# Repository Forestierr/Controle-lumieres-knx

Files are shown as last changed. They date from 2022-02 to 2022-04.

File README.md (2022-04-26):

# controle des lumieres KNX

Controle des lumières de l'atelier ELO avec un écran tactile, un Raspberry et des module ABB et KNX.

L'interace graphique est un site web, réalisé en Python avec Flask.

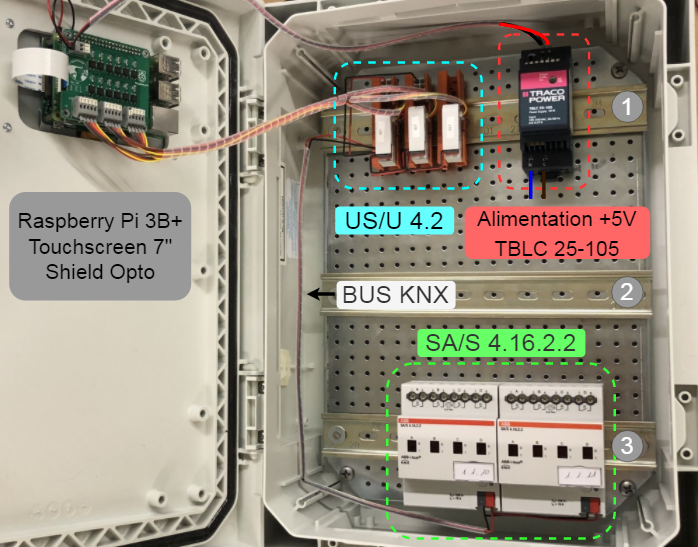
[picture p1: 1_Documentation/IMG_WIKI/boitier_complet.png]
img boitier


##

youtube : https://www.youtube.com/channel/UC0hVF6m1WlG9nCOo1_hOlJg

site : [Zappvion](http://www.zappvion.ch)

## ##
    
<div align="center">
    <i>Robin Forestier</i>
</div>

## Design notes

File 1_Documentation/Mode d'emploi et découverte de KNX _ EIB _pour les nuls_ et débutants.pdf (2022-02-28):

Rechercher

Modes de sujets

mil3d (http://www.knx-fr.com/member.php?action=profile&uid=32)
Super Moderator

Messages : 939
Sujets : 15
Inscription : Jun 2011
Réputation : 0 (http://www.knx-fr.com/reputation.php?uid=32)

#1 (http://www.knx-fr.com/showthread.php?tid=2129&pid=14907#pid14907)

Pages (10) : 1 | 2 (http://www.knx-fr.com/showthread.php?tid=2129&page=2) | 3 (http://www.knx-fr.com/showthread.php?tid=2129&page=3) | 4 (http://www.knx-fr.com/showthread.php?tid=2129&page=4) | 5 (http://www.knx-fr.com/showthread.php?tid=2129&page=5) ... 10 (http://www.knx-fr.com/showthread.php?tid=2129&page=10) | Suivant » (http://www.knx-fr.com/showthread.php?tid=2129&page=2) | Note de ce sujet :
Recherche (http://www.knx-fr.com/index.php) | Liste des membres (http://www.knx-fr.com/memberlist.php) | Carte des membres (http://www.knx-fr.com/usermap.php) | Calendrier (http://www.knx-fr.com/calendar.php) | Aide (http://www.knx-fr.com/misc.php?action=help)
Bienvenue, Visiteur ! | Connexion (http://www.knx-fr.com/member.php?action=login) | S’enregistrer (http://www.knx-fr.com/member.php?action=register)

Forum KNX francophone / English KNX forum (http://www.knx-fr.com/index.php) › Français (http://www.knx-fr.com/forumdisplay.php?fid=3) › Matériel KNX (http://www.knx-fr.com/forumdisplay.php?fid=5)
Mode d'emploi et découverte de KNX / EIB "pour les nuls" et débutants

Mode d'emploi et découverte de KNX / EIB "pour les nuls" et débutants

02/02/2012, 14:00:58 (Modification du message : 07/01/2021, 14:46:56 par filou59.) (http://www.knx-fr.com/member.php?action=profile&uid=1754)

--------------- Afin de préserver ce sujet, merci de ne pas poster ici vos demandes personnelles mais de créer un nouveau sujet ---------------

Bonjour à tous,

Voici un premier essai de présentation de KNX "pour les nuls" et les débutants en électricité et domotique KNX.
Je vais essayer de vous présenter cette très belle technologie appliquée à la domotique résidentielle.

Loin de moi l'idée de me présenter en spécialiste du KNX, ma seule volonté est ici de dégrossir le terrain pour le vrai débutant en KNX qui ne comprend rien à ce qui se dit sur ce forum, et je sais que c'est le cas de beaucoup de nouveaux membres.

Bon courage et bonne découverte !

La théorie... (rapidement !)

Le KNX (anciennement EIB) est un standard de communication appliqué à la domotique résidentielle et industrielle.

Ses points forts?
C'est d'être un standard multimarque, non cantonné à un seul fabriquant (contrairement à la plupart des "standards" en domotique). Le cahier des charges que chaque fabriquant doit suivre et respecter pour apposer le logo KNX sur son produit est très strict, les tests avant validation sont poussés. La qualité des produits semble au rendez-vous tant au niveau de la fiabilité qu'au niveau des possibilités offertes.

Un autre point fort et qui est une spécificité du KNX (même s'il n'est pas le seul l'utilisant), c'est qu'il fonctionne sur le principe de multiples petites intelligences qui communiquent entres-elles plutôt que sur le principe d'un seul cerveau central, qui, en cas de panne, peut rendre toute une installation domotique hors service.

Son point faible ?
Le prix de certains composants (mais souvent à l'image des possibilités et de la qualité offerte).
Bien que vous verrez qu'en choissisant bien ses composants, ce qui semblait impossible peut au final être plus réalisable que prévu.

Bref, le KNX, vous payez le prix,... mais vous êtes rarement déçu.

La pratique... (déjà ?)

Comment allumer une lampe en KNX?
Vous avez besoins de quelques composants indispensables, simplement pour allumer et éteindre une lampe en KNX.
Les voici : (avec leur tarif, ça peut aider tout de suite à savoir si c'est réalisable pour vous ou pas )
1) une lampe avec une ampoule dedans (et qui fonctionne,... oui oui,... c'est indispensable) ; 5 € ça... ça va...
2) un module actionneur KNX (aussi appelé "actuateur") qui actionnera la lampe en ON ou OFF ; à partir de 20€ (si achetés "par 16")
3) un interrupteur : soit un interrupteur KNX, soit un interrupteur bouton poussoir classique (qu'on trouve dans tous les supermarchés) derrière lequel vous placerez un genre "d'adaptateur" KNX ; à partir de 40€ l'interrupteur, pour les plus simples
4) un câble au standard KNX (ou pas) qui reliera tous les participants KNX entre eux (interrupteur, actionneur et alimentation). Il s'agit d'un câble de type câble réseau de couleur verte dont seuls 2 fils sont utilisés (le rouge et le noir); 0,40€/m
5) une alimentation 30V : ceci est plus spécifique à la norme KNX, vous aurez en effet besoin d'une alimentation/d'un transfo pour mettre tout ce beau monde en route, pour les alimenter en électricité via le câble KNX. Attention, on ne parle pas ici d'alimenter l'ampoule, mais bien d'alimenter en 30v les différents modules KNX pour qu'ils puissent fonctionner. Ils seront alimentés en 30v via les 2 fils du câble KNX. Il faut donc que ce câble vert passe aussi par cette alimentation. 170€ l'alimentation pour une petite installation !... mais comptez plutôt 230€ ! Mais pourquoi c'est si cher ??? Je ne sais toujours pas...
6) un peu de câble électrique pour relier les différents appareils en 220v

Voilà, vous avez avec ceci tout ce qu'il faut pour allumer et éteindre une ampoule en KNX (presque tout..., nous le verrons plus bas).

Voici le schéma de montage :

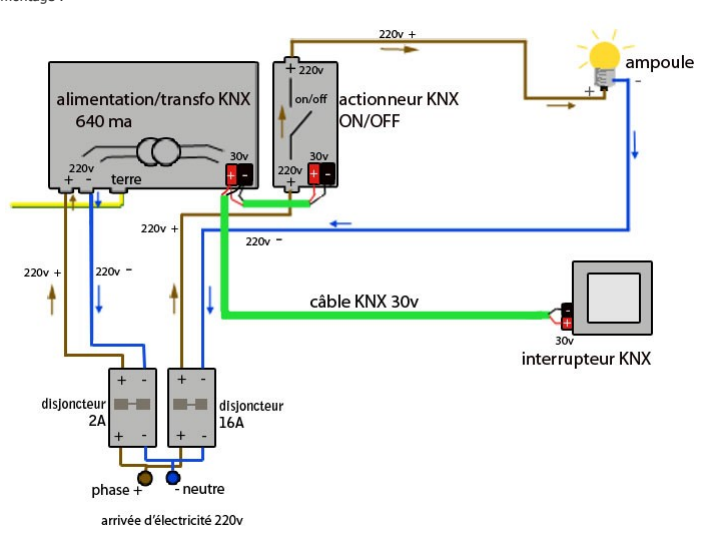
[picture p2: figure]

Quelques explications sur ce schéma :

* L'alimentation KNX (le transfo) transforme donc le 220v en 30v et le transmet via le câble vert à tous les modules KNX. Tous les modules KNX qui s'y trouvent connectés peuvent donc fonctionner.

* Les petits plots rouge et noir que vous voyez sur tous les modules KNX sont des connecteurs WAGO. (http://www.wagocatalog.com/okv3/index.asp?cid=1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) Ils permettent de connecter le câble KNX vert de toutes les manières possibles entre les différents modules KNX. Il y a en effet une très grande liberté dans la manière dont ce câble KNX vert passe d'un module à l'autre. Du moment que vous respectez la polarité +/- (les couleurs des fils rouge/noir), vous pouvez les connecter en parallèle, en étoile, en série,... tout est permis (dans la limite du respect de la norme, notamment sur les longueurs maximum de câble,... que vous n'atteindrez jamais dans une maison). Attention aussi de ne jamais créer de boucle fermée avec le câble KNX !
Grâce à ces plots rouge et noir, vous pouvez connecter jusqu'à 4 câbles vert différents par module KNX, ce qui vous permet une très grande liberté dans le déploiement du câble KNX dans toute la maison. Vous pouvez également acheter d'autres WAGOs de ce type et en placer n'importe où sur le câble pour le "spliter".

* Ce câble vert sert donc à alimenter les modules KNX, mais il sert aussi aux modules pour communiquer entre-eux.
Chaque module KNX possède en effet sa propre intelligence qui lui permet d'envoyer des messages et d'en recevoir, mais aussi de les interpréter pour agir en conséquence.

Dans cet exemple-ci, lorsqu'on va appuyer sur l'interrupteur KNX, celui-ci va envoyer un message 'ON' sur le câble vert (on dit qu'il envoi un message sur le BUS). (http://fr.wikipedia.org/wiki/R%C3%A9seau_en_bus) Tous les modules présents sur ce câble vert (sur le BUS) vont recevoir le message 'ON', mais seul le module actionneur va tenir compte du message et va allumer la lampe. Il est le seul à tenir compte du message parce que vous l'aurez programmé comme cela. Vous aurez programmé le module actionneur pour réagir au message envoyé par cet interrupteur là.

Voici une autre manière très parlante d'exprimer ce qui se passe sur le bus, proposé par un membre du forum (silverrcx) : Le câble vert est un "bus" de donnée, donc tout le monde y va de son petit message, tout le monde le reçoit et n'en fait rien (souvent) ou qqch (parfois). Quand tu appuie sur la touche de l'interrupteur, il "crie" [bouton 23 appuyé] sur le bus et il y a (ou pas) un récepteur (souvent un relais) qui se dit "ah mais dis donc 23 c'est moi ça! Paf j'enclenche le relais".

* Autre détail sur le schéma : pour ceux qui débutent en électricité, vous remarquez que seul le câble + passe par l'actionneur KNX. En effet, pour allumer ou éteindre une lampe, il suffit d'ouvrir ou de fermer un seul fil pour que la lampe s'allume ou s'éteigne. Il n'est donc pas nécessaire de faire passer les 2 fils + et - via l'actionneur KNX. Le câble - va directement à l'ampoule.
Ce principe n'a rien à voir avec la domotique, c'est un principe classique en électricité, appliqué à (presque) tous les interrupteurs classiques dans une maison (exceptés les interrupteurs dis bi-polaires).

* les disjoncteurs se branchent toujours avant tout actionneur (ou dimmer) KNX. Il faut voir les modules KNX comme des interrupteurs classiques, qui sont toujours branchés après les disjoncteurs.

* Il faut également mettre l'alimentation sur un disjoncteur, et de préférence un disjoncteur à part. Comme ça en cas de problème sur une ligne d'éclairage (cours circuit pendant que vous changez une ampoule par ex.), toute l'installation KNX n'est pas coupée à cause du disjoncteur de la ligne d'éclairage qui au sauté.
Le disjoncteur 2A sur le schéma est suffisant dans ce cas car il n'y a que l'alimentation KNX dessus. Mais vous auriez pu mettre un disjoncteur 16A. Il faut savoir qu'un disjoncteur ne sert pas à protéger le matériel qui est branché après lui mais simplement à protéger le câble de toute surtension. En effet, si vous branchez un moteur de 10.000w (ou 5 de 2000w) sur un câble 2,5mm², le câble va fondre. Le disjoncteur sert donc à couper l'alimentation en cas de trop forte demande sur le câble.

Il ne faut pas non plus sous-dimensionner le disjoncteur car sinon quand vous brancherez du matériel de trop forte puissance le disjoncteur sautera. Il faut dimensionner un disjoncteur par rapport au câble qui est utilisé après lui (1,5 - 2,5 - 6 ou 10 mm²,), mais aussi par rapport à ce qui sera demandé comme puissance sur le câble.

Ne pas hésiter à demander l'aide d'un électricien quand on ne connait pas bien les règles de dimensionnement des disjoncteurs, câbles, différentiels, etc. Ce n'est pas évident, c'est un métier. Je peux donner quelques conseils, mais je ne pousserais pas quelqu'un à faire ça tout seul, ça peut être dangereux. Surtout que les règles changent et sont différentes d'un pays à l'autre !

Je sens qu'il manque quelques chose pour faire fonctionner mon installation... Ho zut, c'était trop beau!...

En effet,... si tout est déjà programmé, ce qui est présenté ci-dessus fonctionnera très bien. Mais le soucis, c'est qu'il faut bien les programmer tous ces modules KNX la première fois que vous allez les installer. Et là c'est un peu plus difficile à avaler pour le portefeuille!

* Il existe différents systèmes pour programmer les modules KNX. Le plus communément utilisé, c'est le PC sur lequel vous aurez installé LE programme INDISPENSABLE vendu par l'association KNX.org. Ce programme c'est ETS (actuellement version 5.0, mais les versions 3.0f et 4 sont toujours utilisées). Il s'agit d'un programme qui a été créé au départ pour les professionnels de la domotique, qui gagnent de l'argent avec leur entreprise. Vous ne vous étonnerez donc pas qu'ETS soit vendu près de 1000€ HT ! Impensable me direz-vous ? Il est pourtant indispensable pour programmer votre installation. Une solution est de trouver une âme charitable qui pourra vous prêter sa licence le temps de programmer votre installation. Essayez éventuellement via ce forum, en contactant directement un forumeur près de chez vous... sans garantie bien entendu.
Il est aussi possible d'acquérir une licence ETS lite à 200€ (http://www.knx.org/be-fr/logiciel/ets/prix/index.php) (voir moins cher pour ceux qui souhaitent passer le ETS eCampus) (http://www.knx.org/be-fr/formation/knx-eacademy/ets-ecampus/index.php) qui peut convenir pour une petit projet de type résidentiel même s'il dépasse les 20 participants (en créant plusieurs projets ETS qui utilisent les mêmes adresses de groupe).

* Ce qu'il manque aussi à l'installation décrite sur le schéma ci-dessus, c'est le moyen de faire communiquer le PC (et son programme ETS) avec les modules KNX. Pour cela, vous devez acquérir un module USB ou Ethernet (IP) qui servira de passerelle (+- 180€).
Là, vous n'y couperez pas, c'est non seulement utile pour programmer les modules KNX, mais aussi si vous souhaitez profiter de votre installation et de toutes ses possibilités de communication vers l'extérieur.
Cela permettra par exemple de mettre en place ce qui est communément appelé sur le forum 'une visu', soit une interface visuelle sur PC ou tout autre solution à base d'écran, qui permet d'avoir un aperçu, un suivi visuel de toute votre installation domotique.

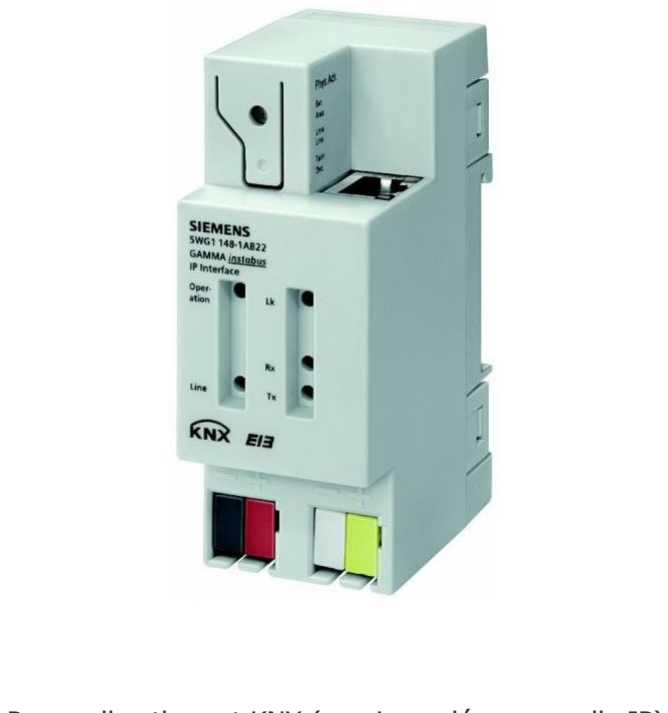
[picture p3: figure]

Passerelle ethernet KNX (aussi appelée passerelle IP)

ATTENTION lors de vos achats de ne pas confondre passerelle IP KNX (ou interface IP KNX) et Routeur KNX.
- la passerelle IP KNX (ou interface IP KNX) est ce dont vous avez besoin pour programmer vos modules KNX sur le BUS ou pour faire de la "visualisation"
- le routeur/coupleur IP KNX sert à faire communiquer 2 bâtiments qui auraient chacun une ligne KNX et dont le seul lien physique possible est un câble réseau ethernet. Cela crée un "tunnel IP" dans lequel passent les messages KNX d'une ligne de bus KNX à l'autre. En plus de cette fonction, certains routeurs IP permettent malgré tout une utilisation comme interface de programmation via ETS ou pour faire de la visualisation.

La fin... (déjà ?)

Voici que se termine un premier aperçu d'une installation simple en KNX. Avec cela, vous pouvez déjà comprendre comment cela fonctionne et les grands principes du système EIB/KNX. A partir de là, vous comprendrez peut-être un peu mieux de quoi discutent tous ces forumeurs aguéris qui balancent des termes comme BUS, visu, actuateurs, etc.

La suite..! La suite....!!

Quelques informations lancées (jetées) au hasard pour les débutants :

Les différentes alimentations
Les alimentations KNX existent en 160ma (milliampère), 320ma et 640ma. Les modules KNX, pour être certifiés, doivent consommer au maximum 10ma chacun. Vous pouvez donc déduire avec cela qu'une alimentation de 160ma peut faire fonctionner sur sa ligne (son câble vert) 16 modules au
maximum, une de 320ma, 32 modules et une de 640ma, 64 modules. Si vous avez un minimum de moyens, achetez directement une 640ma, on arrive vite à 64 modules dans une maison.
Si vous avez plus de 64 modules dans votre maison, vous devez utiliser un coupleur de ligne.

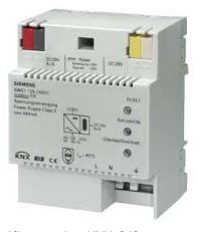
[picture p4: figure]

Alimentation KNX 640ma

Sur cette alimentation, vous voyez le WAGO rouge et noir, mais il y a aussi un WAGO blanc et jaune. En effet, certains modules KNX ne peuvent pas se contenter des 10ma qu'ils sont autorisés à prendre sur le BUS pour fonctionner. On doit donc leur adjoindre une alimentation secondaire 30v. L'exemple type, c'est la passerelle IP que vous pouvez voir plus haut. Elle possède aussi les WAGOs blanc et jaune. Il suffit d'utiliser les fils blanc et jaune du câble vert KNX pour alimenter secondairement la passerelle IP. Ces fils blanc et jaune ne sont actuellement pas utilisés en domotique KNX. Ils sont là "pour réserve" en cas d'évolution de la norme.

*Attention que cette sortie 30v secondaire n'a pas les mêmes propriétés que la sortie 30v rouge et noir du BUS KNX. Elle ne peut pas être utilisée pour cela.
*Attention aussi que toutes les alimentations KNX n'ont pas de sortie 30v secondaire.
*Certaines alimentations ont par contre 2 sorties 30v rouge et noir pour alimenter 2 lignes de BUS différentes (il faudra utiliser malgré tout un coupleur de BUS)
pff, c'est compliqué tout ça !!

Le coupleur de ligne (coupleur de BUS)
Il existe des coupleurs de ligne. Une ligne KNX est l'ensemble des modules KNX connectés entre-eux par "le même" câble KNX. Comme on peut avoir maximum 64 participants (modules KNX) sur une ligne puisque les alimentations font maximum 640ma, vous pouvez utiliser ces coupleurs de ligne pour que 2 lignes puissent communiquer entres-elles. En effet sans cela, un message envoyé par un participant situé sur la ligne 1 (sur l'alimentation n°1) n'arriverait jamais au participant situés sur la ligne 2 (sur l'alimentation n°2) qui attend ce message.

Il existe aussi un type de coupleur de ligne via réseau IP que l'on appelle routeur/coupleur IP KNX. Comme dit plus haut (à propos des interfaces IP KNX), il sert à faire communiquer 2 bâtiments qui auraient chacun une ligne KNX et dont le seul lien physique possible est un câble réseau ethernet. Cela crée un "tunnel IP" dans lequel passent les messages KNX d'une ligne de bus KNX à l'autre.

C'est quoi "une entrée KNX"?... et "une sortie"?
En domotique KNX, on parle souvent "d'entrées" et de "sorties" KNX :

Grossièrement, une "sortie KNX" c'est un module KNX fait pour effectuer une action suite à un ordre/un message KNX. Exemples de sorties KNX :
- les actionneurs (comme présenté sur l'exemple ci-dessus)
- les dimmers.

Les entrées KNX sont l'inverse. Elles sont faites pour "écouter" une action extérieure au KNX et crée un message/un ordre à partir de ce quelle ont reçu comme information "de l'extérieur".
Exemples d'entrées KNX :
- un interrupteur KNX attend qu'on lui pousse dessus pour envoyer l'ordre sur le BUS KNX d'allumer une lampe;
- un modules KNX détecteur de mouvement enverra sur le BUS KNX l'ordre d'allumer une lampe quand il verra passer quelqu'un;
- un module détecteur de température enverra sur le BUS KNX l'ordre d'allumer le chauffage lorsque une t° donnée sera atteinte.

Où trouver mon matériel?
Vous pourrez normalement trouver votre matériel auprès d'un revendeur en électricité un peu spécialisé près de chez vous. Mais le marché KNX est assez peu développé en France et en Belgique ce qui a tendance à tirer les prix vers le haut.

Par contre en Allemagne, c'est le contraire. Beaucoup de forumeur achète leur matériel en Allemagne via internet. C'est souvent moins cher et le service est toujours de qualité (d'après mon expérience).
--> Voici le site le plus connus : www.eibmarkt.com.
Ils font de très bons prix, mais ce n'est pas évident de trouver un article à cause d'un site pas très pratique à utiliser.
--> Ebay Allemagne (http://www.ebay.de) est très fourni en matériel KNX d'occasion. Il faut par contre savoir parler Allemand (plus difficile)... ou savoir utiliser GoogleTranslate (plus facile ). Utilisez les mots-clés EIB ou KNX pour trouver tous les articles KNX.

Petite aide déjà : en allemand,
- actionneur se dit "Schaltaktor",
- dimmer se dit "Dimmaktor".
- "4fach" se traduit par x4 (fois 4)
Donc "Schaltaktor 4fach" veut dire que c'est un actionneur possédant 4 sorties.

Je pense que certains revendeurs ou sites internet en France tentent de s'aligner sur les prix Eibmarkt. A vous de comparer et éventuellement d'essayer de négocier. Je ne peux pas vous guider n'ayant pas essayé.

La problématique des interrupteurs en KNX
Le choix d'un interrupteur en KNX est un vrai dilemme. Entre prix, esthétique, fonctionnalité,... rien n'est simple ! Il y a tellement de possibilités et de choix à faire. Le plus important est de savoir ce que vous voulez réellement faire aux différents endroits où vous en placerez un. Il reste à trouver celui qui rassemblera tous vos critères.

Attention que lorsque vous avez choisi une marque et un modèle d'interrupteur précis, ils sont bien souvent (pas toujours) vendu en 2 pièces détachées :
- L'interrupteur en lui même qui ne représente bien souvent que la partie visible, décorative, placée devant le mur ;
- Le coupleur de bus qui est la partie derrière l'interrupteur qui sert à communiquer avec le BUS KNX, à envoyer les ordres/messages aux autres pariticipants KNX.
Ne vous laissez pas abuser par des interrupteurs dit KNX à 25 euros, qui ne représente souvent que la partie visible auquel il faudra ajouter le coupleur de BUS.

Certains interrupteurs sont très complexes avec écran "de visualisation", thermostat, écran tactile,... les prix sont en correspondance avec la complexité.

La solution que j'ai retenue pour ma part, c'est d'utiliser un interrupteur classique de type bouton poussoir qu'on trouve dans le commerce. Ce choix je l'ai fait principalement pour raison esthétique (je n'aime pas l'esthétique de la plupart des interrupteurs KNX abordables).
Pour communiquer avec le BUS KNX, j'utilise un module d'entrée KNX (voir ci-dessus ce qu'est une entrée KNX) que je place derrière l'interrupteur. Ce module d'entrée est alimenté par le BUS KNX, il n'a donc besoin de rien d'autre que le câble KNX vert pour fonctionner. En plus des WAGOs rouge et noir qui servent à se connecter au BUS, il possède 2 fils que je connecte au bouton poussoir et qui lui serviront à détecter tout appuis sur ledit bouton. A moi de programmer les actions à effectuer selon les appuis détectés.

Les modules que j'ai retenus sont des ABB US/U 2.2, US/U 4.2 et US/U 12.2 (pour 2, 4 ou 12 entrée/sorties possibles).
Pourquoi "entrées/sorties"? Parce qu'en plus de pouvoir détecter l'appui sur un bouton poussoir, ces modules ABB US/U sont capables aussi d'allumer une led "à la demande". Ces leds, en les plaçant juste derrière la "fenêtre" de l'interrupteur, permettent de signaler l'un ou l'autre évènement aux personnes situées dans la pièce (oubli d'une lampe dans la cave,...)

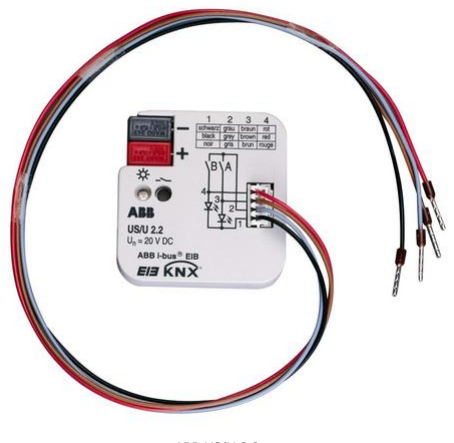
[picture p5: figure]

ABB US/U 2.2

Quel câble KNX ?
Pour votre câble KNX, vous pouvez utiliser du câble certifié KNX (le fameux câble vert). C'est franchement recommandé.
Mais à 0.40 € le mètre, certains souhaitent économiser sur ce point. Ils utilisent donc du câble réseau CAT5e, bien moins cher. Apparemment ça fonctionne. Attention d'utiliser du câble réseau avec des brins rigides, pas de brins souples. Sinon ils ne rentreront pas dans les wagos rouge et noir.

KNX, ça existe sans fil ?
Oui il existe plusieurs solutions de KNX sans fil par onde radio, mais ce sont plutôt des sous réseaux au sein du protocole KNX.

En effet, lorsque vous choisissez une marque d'émetteur/récepteur sans fil (le module KNX qui servira de passerelle entre les modules sans fil et le réseau KNX filaire), seuls les modules sans fil de cette marque là pourront passer par l'émetteur/récepteur en question. En clair, si vous choisissez un émetteur/récepteur HAGER, vous devrez acheter les télécommandes de la marque Hager.

Mais une fois le lien entre le réseau filaire KNX et le réseau sans fil effectué grâce à l'émetteur/récepteur, la communication est transparente entre les modules KNX filaires et les modules KNX sans fil (pour certaines marques tout du moins, pas dans toutes les marques !)

L'exemple d'un très bon réseau sans fil que je connais et que j'utilise quotidiennement est le réseau sans fil Hager avec son coupleur de média TR131a (http://www.eibmarkt.com/cgi-bin/eibmarkt.storefront/EN/Product/NS6509694?PID=EN_NS6509694) (émetteur/récepteur). Associé aux télécommandes TU402, (http://www.eibmarkt.com/cgi-bin/eibmarkt.storefront/EN/Product/NS6508682?PID=EN_NS6508682) TU404, (http://www.eibmarkt.com/cgi-bin/eibmarkt.storefront/EN/Product/NS6508683?PID=EN_NS6508683) TU406 (http://www.eibmarkt.com/cgi-bin/eibmarkt.storefront/EN/Product/NS6508684?PID=EN_NS6508684) et TU418 (http://www.eibmarkt.com/cgi-bin/eibmarkt.storefront/EN/Product/NS6508685?PID=EN_NS6508685) (pour 2, 4, 6 et 18 boutons), cela fait un très efficace réseau sans fil pour télécommander la maison.
Ces télécommandes sont très esthétiques (question de goût), et très efficaces point de vue longueur de portée (au fond de mon jardin à 60m, j'allume toujours la lampe du salon).

Il existe chez Hager d'autres modules d'entrées sans fils que les télécommandes pré-citées : boutons poussoirs, modules d'entrées à contacts secs,... ainsi que des modules de sorties sans fil : actionneurs, dimmers,...

Attention encore une fois que toutes les marques ne permettent pas une communication bi-canal (émetteur/récepteur). Certaines se limitent en effet au simple transfert des messages KNX venant du réseau sans fil vers le KNX filaire et ne permettent donc pas l'envoi d'ordres KNX venant du filaire vers le réseau KNX sans fil. Cela fait une grande différence de souplesse (par exemple en cas de souhait d'évolution de votre installation domotique, si vous souhaitez installer un jour un actionneur à un endroit non prévu à l'origine et qu'il n'y a pas de câble KNX vert à proximité).

Quel matériel de base choisir dans tout ce choix de marque et de modèle?
Voici quelques exemples concrets de matériel KNX à prix raisonnable, pour des fonctionnalités classiques et approuvées :
Alimentation Siemens 640ma 5WG1125-1AB21 (http://www.eibmarkt.com/cgi-bin/eibmarkt.storefront/EN/Product/NS0821503?PID=EN_NS0821503)
Passerelle IP Siemens 5WG1148-1AB22 (http://www.eibmarkt.com/cgi-bin/eibmarkt.storefront/EN/Product/NS6508760?PID=EN_NS6508760) Cette passerelle IP a longtemps été recommandée car elle est très répandue sur le marché KNX, ce qui la rend compatible de manière plus sûr dans la plupart des applications ("visus", matériel,...). Elle semble cependant aujourd'hui détrônée par des passerelles plus récentes. Un post sur le forum créé par Filou59 l'explique en détail ici (http://www.knx-fr.com/showthread.php?tid=6485)

Edit 10/2020 : Ce modele est enfin arrété par Siemens, raison de plus pour ne plus le choisir même si certains fournisseur la propose encore.

Actionneur On/Off Siemens 16 sorties 5WG1567-1AB22 (http://www.eibmarkt.com/cgi-bin/eibmarkt.storefront/EN/Product/NS6508387?PID=EN_NS6508387)
Module dimmer JUNG FUD 4252 4 sorties 50w-210w (http://www.eibmarkt.com/cgi-bin/eibmarkt.storefront/EN/Product/NS6506531?PID=EN_NS6506531)

Module d'entrée/sortie ABB US/U 2.2 (http://www.eibmarkt.com/cgi-bin/eibmarkt.storefront/EN/Product/NS0819733?PID=EN_NS0819733) pour, par exemple, interrupteur
Détecteur de présence 360° et mesure de luminosité (http://www.eibmarkt.com/cgi-bin/eibmarkt.storefront/EN/Product/N000530?PID=EN_N000530) de marque Eibmarkt (attention, ce n'est pas un détecteur de mouvement, c'est plus sensible !) Câble KNX vert par 100m (http://www.eibmarkt.com/cgi-bin/eibmarkt.storefront/EN/Product/NS0140116?PID=EN_NS0140116)
Pour le KNX sans fil de marque HAGER, voir les liens au point précédent

C'est quoi une "platine de test"? à quoi ça sert?
Avant de vous lancer dans l'achat de tout votre matériel KNX qui peut coûter des milliers d'euros, il serait vraiment très sage d'acheter quelques éléments pour les tester, pour vérifier qu'ils fonctionnent ensembles et comme vous le souhaitez. Achetez au minimum le matériel décrit dans l'exemple du début de ce post + un exemplaire des quelques éléments spécifiques à votre installation que vous souhaitez intégrer.

Une fois que tout aura été testé et validé, que vous vous sentirez à l'aise avec vos choix et la programmation des modules, il sera bien temps de vider votre compte en banque en achetant le reste.

Comment savoir si un module KNX me conviendra?
Vous avez de la chance, avant d'acheter un module KNX vous pouvez savoir tout ce qu'il a dans le ventre, du moins en termes de fonctionnalités.

Le cher (!) programme ETS nécessaire à la programmation des modules KNX permet en effet de visualiser toutes les fonctionnalités d'un module KNX que vous ne posséderiez pas encore. Il suffit pour cela d'aller sur le site internet du fabriquant du module en question et de télécharger sa base de données de produits KNX. Vous intégrez cette base de données dans la base de données ETS et vous pouvez ainsi avoir accès à toutes les propriétés et possibilités des différents produits.

Par exemple, vous pourrez savoir si un dimmer permet l'allumage d'une lampe sur 10 secondes, savoir si un interrupteur permet une action spécifique sur un double appui, etc...

Et pour la partie visualisation de mon installation (la visu)?
Le trio de logiciel libre le plus connu sur ce forum est EIBd, LinkKNX et KNXweb (dans sa version 2 actuellement). Une section entière leur est consacrée. (http://www.knx-fr.com/forumdisplay.php?fid=10)
Mais vous avez aussi des solutions toutes prêtes comme le Gira HomeServer, Domovea, LifeDomus,... (désolé pour les autres, j'ai pas fait d'enquête) Pour les programmeurs sous Windows, vous pouvez aussi créer votre propre programme pour gérer votre installation grâce au SDK Falcon.net créé par l'association KNX (il est gratuit)

Tutoriel ETS 3.0 et tutoriel ETS 4

Un tutoriel ETS 3.0 : http://sitelec.org/download_page.php?fil...ts_erm.pdf

Et un très bon tutoriel ETS 4.0 (et KNX en général) proposé par un membre du forum : Le sujet de discussion : http://www.knx-fr.com/showthread.php?tid=2241
Le tutoriel en question : http://www.knx-fr.com/attachment.php?aid=84

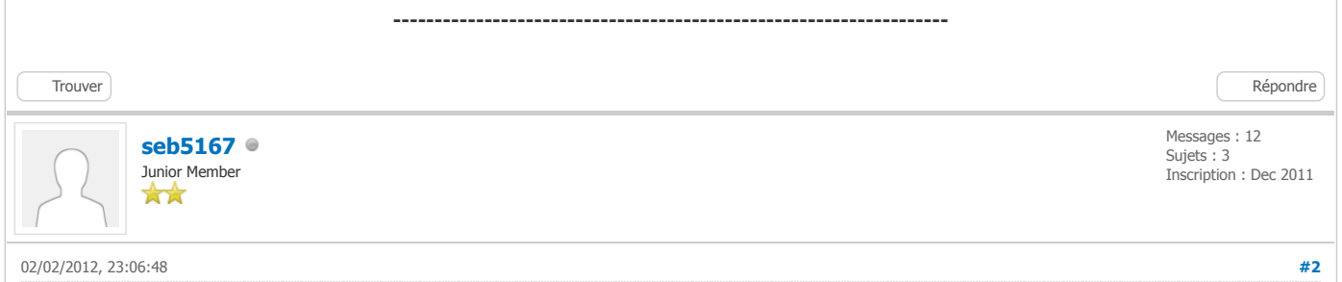
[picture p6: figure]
Trouver; Répondre; seb5167; Junior Member; Messages : 12 Sujets : 3 Inscription : Dec 2011

Waou!! joli post ! merci mil3d
J'avais déjà tout découvert tout seul ou presque. Tu aurais pu venir 8mois plus tôt

Concernant la visu, j'utilise ligo.tv c'est le seul que j'ai réussi à faire fonctionner malgré les dizaines heures passées sur linknx et knxweb.
Non de dieu, quand y aura t il quelqu'un qui postera un VM fonctionnelle avec un ubuntu récent le trio infernal (pour moi) et des lignes de commandes

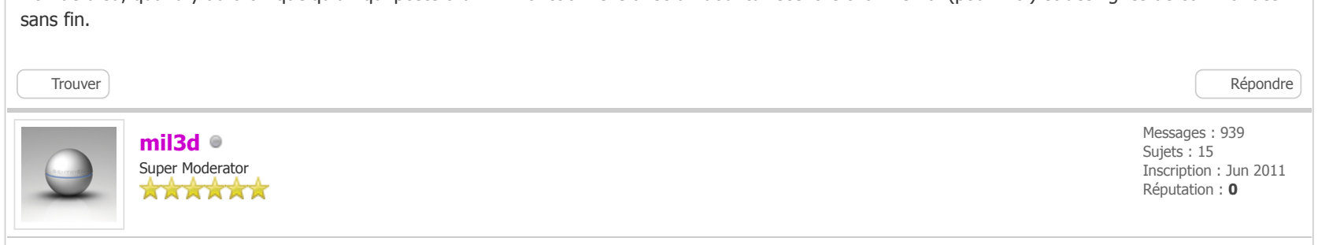
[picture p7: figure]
Trouver; Répondre; mil3d; Super Moderator; Messages : 939 Sujets : 15 Inscription : Jun 2011 Réputation : 0; sans fin.

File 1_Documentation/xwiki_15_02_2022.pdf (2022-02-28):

# Controle des lumières KNX

last modified by Forestier Robin
on 2022/02/22 08:19

Projets - Controle des lumières KNX

- 1.0 - But
- 2.0 - Liens
- 3.0 - Composants
- 4.0 - Schéma Bloc
- 5.0 - Shield Opto
- 5.1 - Shéma Shield Opto
- 5.2 - PCB Shield Opto
- 6.0 - GUI
- 6.1 - Utilisateurs
- 6.2 - Pages
- 6.2.1 - Login
- 6.2.2 - page1
- 6.2.3 page 2
- 6.2.4 - Settings
- 6.2.5 - téléphone
- 7.0 - Programmation
- 7.1 - Code Python
- 7.1.1 - Config
- 7.2 - HTML
- 7.3 - CSS
- 8.0 - Instalation du Raspberry
- 8.1 - Instalation
- 8.1.1 - Image
- 8.1.2 - Git clone
- 8.1.3 - Configuration
- 8.1.4 - Configuration Gunicorn
- 8.1.5 - Création du certificat SSL
- 8.1.6 - Configuration NGINX
- 8.1.7 - Lancement Navigateur
- 9.0 - Sauvgarde de l'image
- 9.0 - Câblage
- 10.0 - Mécanique
- 10.1 - Fixation

Page 2 / 24 - last modified by Forestier Robin on 2022/02/22 08:19

# 1.0 - But

Le but de ce projet est de réaliser une interface graphique pour le contrôle des lumières de l'atelier.
Un écran Raspberry Pi 7" Touchscreen Display servira de contrôleur principal, directement branché sur un Raspberry Pi 3b+.
Une interface à l'aide d'optocoupleurs est utilisée et directement contrôlé par les GPIO du Raspberry.
Pour le contrôle des lumières, nous utilisons deux types de module, trois US/U 4.2 de ABB et deux SA/S 4.16.2.2.

# 2.0 - Liens

Gitlab (http://http://172.16.32.230/Forestier/controle-des-lumieres-knx)
ABB - US/U 4.2 (https://new.abb.com/products/fr/GHQ6310070R0111/us-u4-2)
ABB - SA/S 4.16.2.2 (https://new.abb.com/products/fr/2CDG110262R0011/sa-s4-16-2-2)
Explication KNX (http://www.knx-fr.com/showthread.php?tid=2129)

# 3.0 - Composants

Pour le projet :
Nom | Nombre | Prix unité | Prix tolal
Raspberry Pi 3B+ | 1 | 40.90 | 40.90
Raspberry Pi 7" Touchscreen 1 | 74.90 | 74.90
US/U 4.2 | 3 | 83.80 | 251.40
SA/S 4.16.2.2 | 2 | 169.60 | 339.20
TBLC 25-105 | 1 | 52.00 | 52.00
Fibox ARCA 403015 | 1 | 96.90 | 96.90
Total | | | 857.30
Pour la carte Shield Opto :
Reference | Value | Prix unité | Prix total
K2-K13 | ASSR-1218 | 1.75 | 21
x1-x3 | WAGO 218-505 | 3.25 | 9.75
x4 | WAGO 218-502 | 1.55 | 1.55
Total | | | 32.30

Page 3 / 24 - last modified by Forestier Robin on 2022/02/22 08:19

# 4.0 - Schéma Bloc

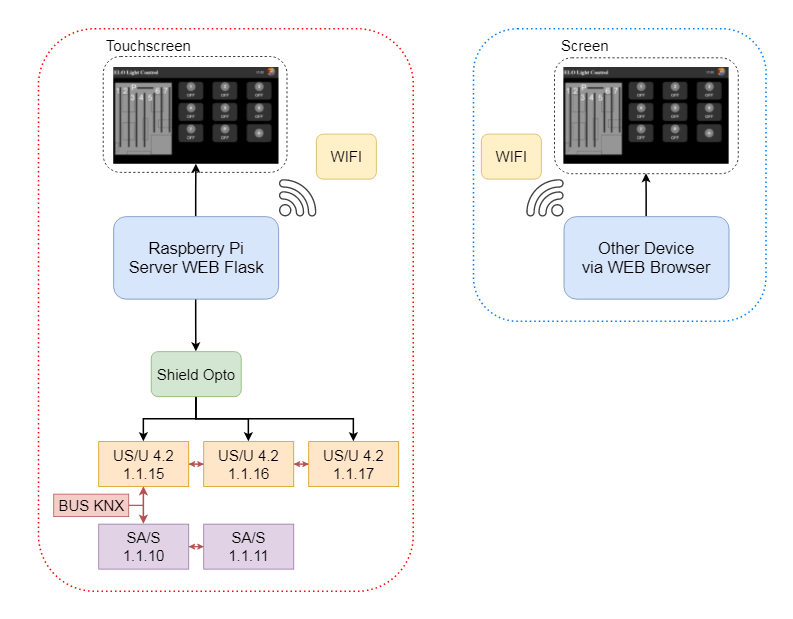
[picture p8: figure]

Comme on peut le voir sur ce shéma block, on utilise plusieurs systèmes de communication. Les Gpio du Raspberry contrôl directement le shield opto puis les US/U 4.2.
Les SU/U 4.2 communiquent avec les SA/S en KNX (www.knx.ch).
Et les autres appareils communiquent en TCP via le wifi.

Page 4 / 24 - last modified by Forestier Robin on 2022/02/22 08:19

# 5.0 - Shield Opto

Pour contrôler les modules US/U 4.2 de chez ABB, nous utilisons des Optocoupleurs mosfet contrôlés par les GPIO du Raspberry. J'ai donc réalisé le shield opto qui vient directement se brancher sur le Raspberry pour faciliter le cablâge et minimiser l'espace.

## 5.1 - Shéma Shield Opto

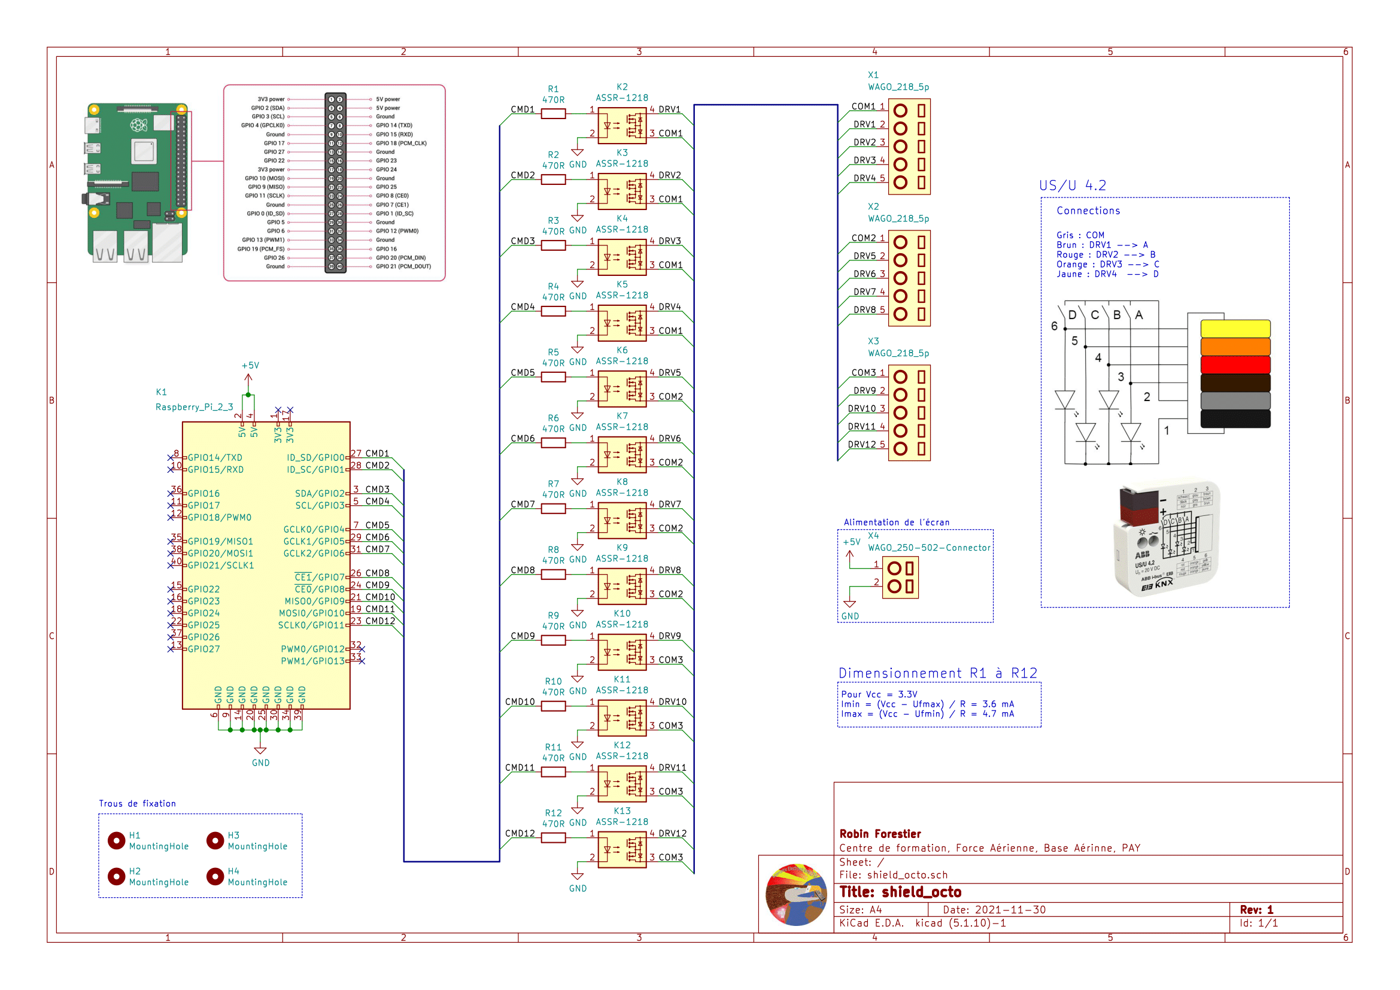
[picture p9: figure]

Page 5 / 24 - last modified by Forestier Robin on 2022/02/22 08:19

## 5.2 - PCB Shield Opto

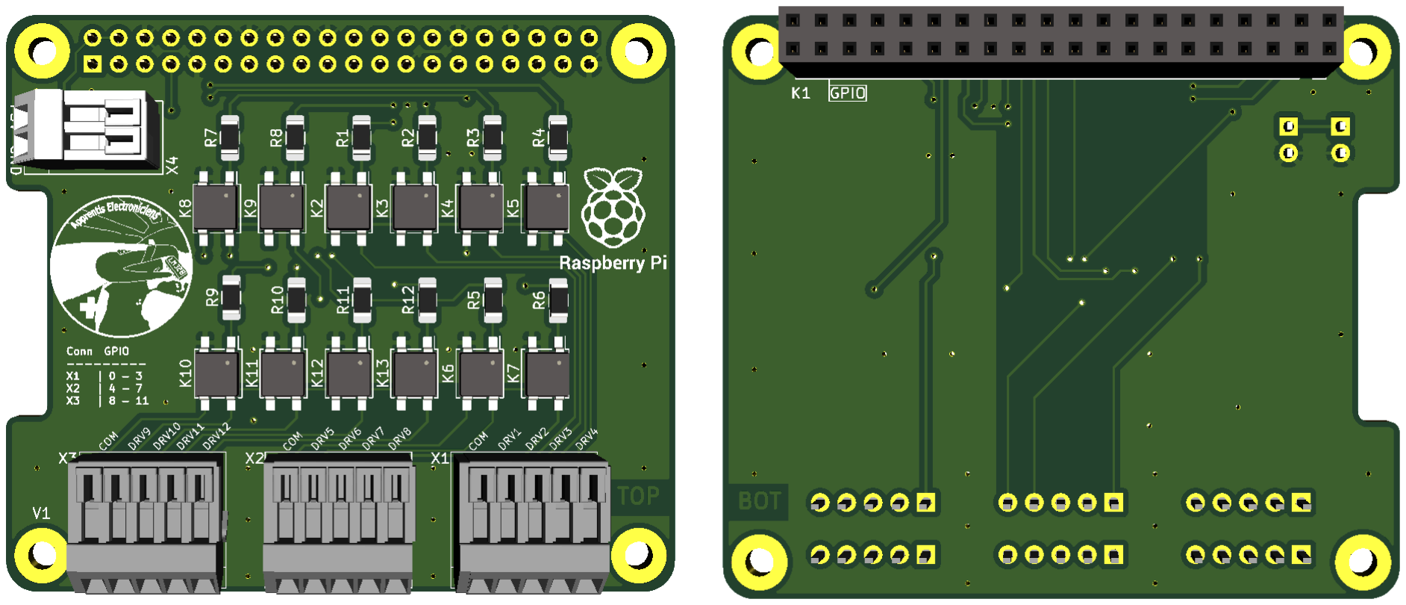
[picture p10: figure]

# 6.0 - GUI

Pour la partie graphique, j'ai tout d'abord essayé avec la librairie Python TKinter. https://docs.python.org/fr/3/library/tkinter.html
Les versions de test se trouvent sur sur le gitlab sous 5_Programmation.
Mais pour simplifier le tout et pouvoir dans le futur ajouter une partie réseau à ce projet, j'ai donc choisi d'héberger un site web. En utilisant Flask sur Python, je peux donc facilement héberger le site sur mon Raspberry pi et me connecter dessus simplement en connaissant l'adresse IP.

## 6.1 - Utilisateurs

Pour assurer la sécurité du site, il existe 3 utilisateurs différents.
1: elo
L'utilisateur elo peut, s'il connaît le mot de passe, allumer ou éteindre les lumières sans pouvoir accéder aux paramètres.
2: admin
L'utilisateur admin a tous les accès.
3: local
Cet utilisateur est réservé au Raspberry pi (server).
L'utilisateur local n'a pas besoin de se connecter pour accéder au site, son authentification se fait à l'aide de son IP. Il ne peut pas accéder aux réglages de l'application.

Page 6 / 24 - last modified by Forestier Robin on 2022/02/22 08:19

## 6.2 - Pages

Le site est constitué de 4 pages distinctes.
6.2.1 - Login
La page de login permet de se connecter via un périphérique autre que l'écran tactile.

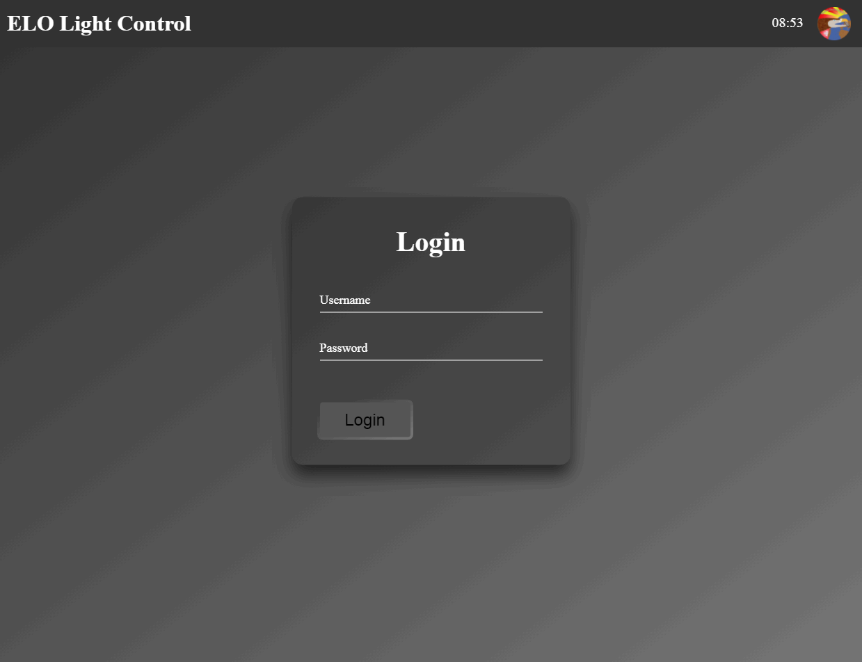
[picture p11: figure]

Page 7 / 24 - last modified by Forestier Robin on 2022/02/22 08:19

6.2.2 - page1
La page 1 contient à gauche un plan de l'atelier qui se modifie selon les lumières allumées.
A droite, 9 boutons permettent d'allumer séparément chaque rail de lumières. Le bouton en bas à droite permet de se rendre sur la page 2.
Le logo ELO en haut à droite permet d'accéder aux réglages (admin only).

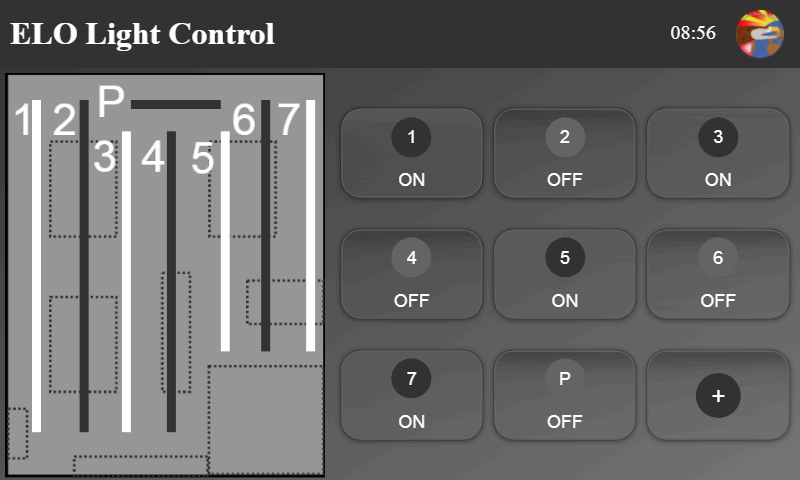
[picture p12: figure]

### 6.2.3 page 2

La page 2 est une copie de la page 1 avec comme modification l'action des boutons de droite. On y retrouve:
- All ON | tout allumer
- ALL OFF | tout éteindre
- 1/2 | allumer 1 sur 2
- G | allumer la gauche de l'atelier
- D | allumer la droite de l'atelier
- N/C | non connecté (réserver pour usage futur)
Le bouton en bas à droite permet de se rendre sur la page 1.

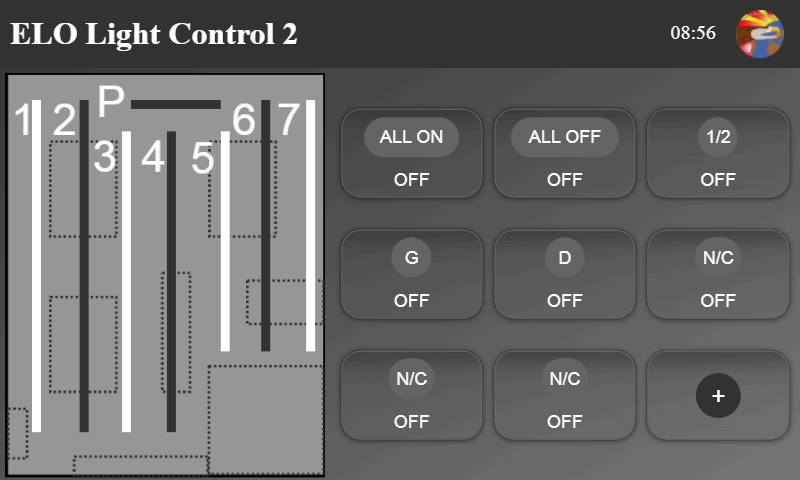
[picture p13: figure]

Page 8 / 24 - last modified by Forestier Robin on 2022/02/22 08:19

6.2.4 - Settings
La page settings accessible uniquement par le compte admin permettra de régler les paramètres importants. 6.2.5 - téléphone
J'ai aussi réalisé une mise en page pour téléphone.

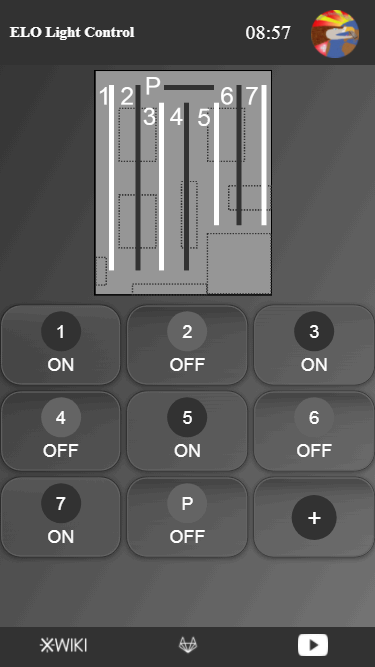
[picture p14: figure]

# 7.0 - Programmation

Pour la programmation de cette interface, j'ai utilisé python. Plus précisément flask. https://flask.palletsprojects.com
Flask est un micro framework open-source de développement web en Python. (Wikipedia)
Avec flask, je peux facilement héberger un server web. Il suffit de créer les fichiers: static & templates. \5_Programmation
│
└──INT_SERV
│
├──static
│ │
│ └──img
│
└──templates
Le programme python se trouve dans le dossier principal (INT_SERV). Les fichers HTML se trouvent dans templates.
Les fichiers CSS se trouvent dans static.
Les images se trouvent dans static\img.
On retrouve aussi le fichier config.csv dans le dossier principal.

Page 9 / 24 - last modified by Forestier Robin on 2022/02/22 08:19

## 7.1 - Code Python

Pour ce code j'ai besoi de ces bibliothèques.
from flask import Flask, render_template, request, session, url_for, redirect, flash, abort from flask_sqlalchemy import SQLAlchemy
from flask_session import Session
import time
import datetime
import threading
import csv
import os
import logging
from werkzeug.exceptions import HTTPException
Quand le Raspberry Pi avec l'écran veut se loger sur le site, on veut que cela soit fait automatiquement. Pour le faire, j'ai créé une liste des IP autorisées.
authorize_ip = ["localhost", "127.0.0.1", "172.16.32.133"]
Pour pouvoir créer une session pour chaque utilisateur se connectant sur le site, j'ai créé une class User. class User:
"""User : creat different user for the login"""
def __init__(self, id, username, password):
self.id = id
self.username = username
self.password = password
Il y a 3 sortes d'utilisateur.
1 - le raspberry pi en local, username = local.
2 - un utilisateur, username = elo.
3 - un admin, username = admin.
users.append(User(id=1, username='elo', password='elo')) users.append(User(id=2, username='admin', password='admin')) users.append(User(id=3, username='local', password='local'))
Chaque page web a sa propre fonction pour pouvoir interagir avec les request. Dans l'ordre, login, page1, page2 et settings.
@app.route("/login", methods=['POST', 'GET'])
@app.route("/", methods=['POST', 'GET'])
def login():
@app.route("/page1", methods = ['POST', 'GET']) def page1():
@app.route("/page2", methods = ['POST', 'GET']) def page2():
@app.route("/settings", methods = ['POST', 'GET'])
def settings():
Pour que l'utilisateur puisse voir quelque chose, il faut lui retourner la page.
On va donc retourner le fichier HTML correspondant à l'aide de la fonction render_template(). On ajoute aussi toutes les variables qui seront affichées sur la page come l'heure (time).

Page 10 / 24 - last modified by Forestier Robin on 2022/02/22 08:19 return render_template('page1.html', button=buttonSts_p1,
color=color,
time=current_time,
warning=warning)
Une dernière fonction est la fonction activate_job().
Cette fonction s'execute au moment où la première personne essaie de se connecter au site.
Un thread est créé pour réaliser toutes les autres activités comme: les automatisations ou le warning de température.
@app.before_first_request
def activate_job():
"""activate_job : fonction to run job on backround of the web server (with thread)""" def run_job():
"""
run_job : run background job (run every minute).
Auto - on/off
Check temperature of the Raspberry Pi
"""
thread = threading.Thread(target=run_job) thread.start()
Et pour finir le main.
if __name__ == "__main__":
logging.info(" *** Strating server *** ") app.run(host='0.0.0.0', port=80, debug=False)
GPIO.cleanup()
7.1.1 - Config
Le fichier config.csv contient les informations pour la page settings.
Ces informations sont stoquées en externe du programme pour assurer qu'elles soient sauvgardées même après un redémarrage.
Pour le moment, les seules informations stoquées sont: Auto on et Auto off.
Ce qui correspond à l'allumage automatique des lumières à une certaine heure.
Voici son contenu :

## 7.2 - HTML

Les fichiers HTML se trouvent sous \5_programmation\nom_de_version\templates On retrouve évidement un fichier HTML par page.
Détaillons le fichier page1.html.
Premièrement, j'utilise une balise meta pour venir reload automatiquement ma page. Ceci permet, en cas de modification d'un autre utilisateur, d'afficher ses dites modification. <meta http-equiv="refresh" content="60">

Page 11 / 24 - last modified by Forestier Robin on 2022/02/22 08:19

Dans le header, on peut voir l'heure affichée à gauche.
Pour le faire, dans mon code python, je viens ajouter time quand j'appelle la fonction render_template(). Et pour l'afficher sur ma page web, il suffit d'écrire { {time} }
<div class="header">
<a href="/settings"> <img src="/static/img/logo.png" alt="logo" width="75%"> </a>
<p> {{ time }} </p>
<p class="warning"> {{ warning }} </p>
<h1>ELO Light Control</h1>
</div>
Vient ensuite le plan de l'atelier. Ce plan est une image où je viens simplement dessiner les néons allumés. Le script récupère la couleur des différents néons et créé un rectangle à la bonne place.
<div class="row" id="row">
<div class="column-l">
<img src="/static/img/plan_vide.png" alt="plan" id="plan" style="display: none"> <canvas id="myCanvas" width="356px" height="451px">
<script>
window.onload = function() {
var c = document.getElementById("myCanvas"); var ctx = c.getContext("2d");
var img = document.getElementById("plan"); ctx.drawImage(img, 0, 0);
ctx.fillStyle = "{{ color[0] }}";
ctx.fillRect(30, 30, 10, 370);
(...)
}
</script>
</canvas>
<noscript>
<p style="color:red">JavaScript is Disable on you brother </p>
<p style="color:red">To have the best use of this site, please turn it on.</p> </noscript>
</div>

Page 12 / 24 - last modified by Forestier Robin on 2022/02/22 08:19

Pour finir, il reste à afficher les boutons.
Pour cela j'ai réalisés une boucle for.
Il faut utiliser Jinja: https://jinja.palletsprojects.com/en/3.0.x/templates/
Puis on crée le dernier bouton pour accéder à la page suivante.
Il faut aussi créer deux faux texte pour qu'il agisse correctement avec les règles css. <form method="post" action="/page1" class="column-r" id="grid">
{% for bt in button %}
<div class="button_num">
<button class="btn" id={{ bt }} type="submit" name="button_p1" value={{ loop.index }}> {% if loop.index == 8 %}
<span class="text_num" id={{ bt }}> P </span>
{% else %}
<span class="text_num" id={{ bt }}> {{ loop.index }} </span> {% endif %}
{% if bt == "off" %}
<p class="text_info"> OFF </p>
{% else %}
<p class="text_info"> ON </p> {% endif %}
</button>
</div>
{% endfor %}
<div class="button_num">
<button class="btn" id="off" type="submit" name="button_p1" value="page_2"> <span class="page_next"> + </span>
<p class="text_on" style="visibility: hidden"> OFF </p>
</button>
</div>
</form>

Page 13 / 24 - last modified by Forestier Robin on 2022/02/22 08:19

## 7.3 - CSS

Les fichiers CSS se trouvent dans \5_programmation\nom_de_version\static. Il y a 3 fichiers css.
style.css - utilisé pour les pages: page1 et page2.
login.css - utilisé pour la page: login.
settings.css - utilisé pour la page: settings.
Il y quelques points importants que je vais expliquer ci-dessous.
Pour l'affichage du plan à côté des boutons, j'utilise deux colonnes (l et r). .column-r {
position: relative;
width: auto;
height: auto;
padding: 10px;
padding-top: 5%;
}
.column-l {
float: left;
width: auto;
height: 100%;
padding: 5px;
margin-top: 20px;
margin-left: 5px;
}
Puis pour afficher les 9 boutons, j'utilise une grille. #grid {
display: grid;
column-gap: 10px;
row-gap: 30px;
grid-template-columns: repeat(3, 1fr);
}
Pour avoir un meilleur affichage sur l'écran du Raspberry, j'ai créé une partie du css exprès. @media all and (max-width: 800px) and (max-height: 480px) and (min-width: 799px) Et j'ai aussi créé un partie pour les téléphones portables.
@media only screen and (hover: none) and (pointer: coarse) and (orientation: portrait)

Page 14 / 24 - last modified by Forestier Robin on 2022/02/22 08:19

# 8.0 - Instalation du Raspberry

## 8.1 - Instalation

Pour l'installation du Raspberry et de la partie logicielle, vous pouvez soit, copier l'image de mon Raspberry et repartir de là où j'ai laissé le projet ou repartir de zéro.
Commençons avec la première méthode.
Pour cela rendez-vous sur le OMVSERVER et sur : formation/project/ControleDesLumiersKNX, récupérer l'image "lightcontrol.img" et copiez la sur votre bureau.
Avec le logiciel Raspberry Pi Imager installer l'image sur une carte micro sd (>= 16Gb).
Pour vous assurer que vous avez la dernière version du programme, il faut réaliser un pull du GitLab.
cd controle-des-lumieres-knx
git fetch
git pull
sudo systemctl restart nginx
Si vous n'avez aucune erreur, redémarez votre Raspberry et votre installation sera terminée. Si vous avez une erreur au git pull, faites simplement : git checkout .
Si vous avez d'autres erreurs testez :
sudo systemctl status lightcontrol
sudo nginx -t

## 8.1.1 - Image

Si vous souhaitez réaliser une installation depuis le départ, voici la marche à suivre. Pour faire fonctionner votre Raspberry, il vous faudra une image.
Vous pouvez simplement télécharger Raspberry Pi Imager. https://www.raspberrypi.com/software/
Ou installer la version se trouvant sur le OMVSERVER. OMVSERVER\formation\Projets\ControleDesLumiersKNX\raspberry_imager_1.7.1.exe Installez-le sur votre PC.
Sur l'interface, choisissez l'image de votre choix puis votre carte micro SD.
Vous pouvez aussi déjà configurer votre Raspberry en cliquant sur la roue dentée en bas à droite. Quand tout est bon, il suffira de cliquer sur écrire.
Vous pouvez maintenant lancer votre Raspberry pi avec sa nouvelle image.
Commencez par le configurer et le connecter au wifi.
Vous pouvez installer Xscreen saver pour désactiver la mise en veille. sudo apt-get install xscreensaver
Puis dans l'app, choisir désactiver la mise en veille.
Vous pouvez aussi activer VNC et le SSH pour vous faciliter la vie. sudo raspi-config

## 8.1.2 - Git clone

Pour cloner le gitlab, copiez cette commande dans votre terminal. (vérifiez s'il n'a pas été déplacé sous Projets_Ancien_Apprentis)
git clone http://172.16.32.230/Forestier/controle-des-lumieres-knx

Page 15 / 24 - last modified by Forestier Robin on 2022/02/22 08:19

Vous trouverez ensuite le dossier de la dernière version du server sous 5_Programmation/server .

## 8.1.3 - Configuration

Tout d'abord, on va installer quelques outils de base.
sudo apt install python3-pip python3-dev build-essential libssl-dev libffi-dev python3-setuptools Maintenant, on va se rendre dans notre dossier server puis installer tous les "requirements".
cd controle-des-lumieres-knx/5_Programmation/server
source serverenv/bin/activate
pip install -r requirements.txt
deactivate
Vous pouvez tester le server en exécutant le flask_test.py dans le dossier server/test.
cd controle-des-lumieres-knx/5_Programmation/server/test
sudo python3 flask_test.py
Pour s'y connecter, tapez l'ip de votre Raspberry dans la barre de recherche de votre navigateur.
Si vous ne connaissez pas l'ip de votre Raspberry, tapez "ifconfig" dans votre terminal.
Vous devriez voir une page blanche avec marqué "Hello World".
Pour que le server WEB se lance automatiquement au démarrage du Raspberry Pi et pour que le server ne soit plus un serveur de développement,j'ai choisi d'utiliser un server Gunicorn, et le proxy Nginx.
Pour l'installation vous pouvez suivre ce tuto : https://www.digitalocean.com/community/tutorials/how-to-serve-flask-applications-with-gunicorn-and-nginx-on-ubuntu-18-04 (https://www.digitalocean.com/community/tutorials/how-to-serve-flask-applications-with-gunicorn-and-nginx-on-ubuntu-18-04)
(/1_Documentation/Flask_server_Gunicorn_DigitalOcean.pdf)
Mais je vais quand même expliquer comment je l'ai fait.
Si tout va bien vous avez normalement dans le dossier server un fichier WSGI.py et un fichier lightcontrol.services.

Page 16 / 24 - last modified by Forestier Robin on 2022/02/22 08:19

## 8.1.4 - Configuration Gunicorn

Commenson la configuration du server. La première chose sera de configurer Gunicorn pour que le server se lance automatiquement.
Pour cela, on va créer le fichier lightcontrol.service.
sudo nano /etc/systemd/system/lightcontrol.service
Puis on y écrit ceci :
[Unit]
Description=Gunicorn instance to serve ELO light control After=network.target
[Service]
User=pi
Group=www-data
WorkingDirectory=/home/pi/controle-des-lumieres-knx/5_Programmation/server Environment="PATH=/home/pi/controle-des-lumieres-knx/5_Programmation/server/serverenv/bin" ExecStart=/home/pi/controle-des-lumieres-knx/5_Programmation/server/serverenv/bin/gunicorn --workers 1 --bind unix:lightcontrol.sock -m 007 wsgi:app
[Install]
WantedBy=multi-user.target
Unit : Description du project
Service : On indique sous quel utilisateur on va utiliser le server et où se trouvent les dossiers. Install : Pour activer le démarrage automatique.
Vous pouvez fermer et enregistrer le fichier.
(ctrl + x puis o puis enter)
On va maintenant démarrer Gunicorn.
sudo systemctl start lightcontrol
On l'autorise à se lancer au démarage. sudo systemctl enable lightcontrol On va "checker" le status.
sudo systemctl status lightcontrol
Vous devriez voir:
- lightcontrol.service - Gunicorn instance to serve ELO light control
Loaded: loaded (/etc/systemd/system/lightcontrol.service; enabled; vendor preset: enabled) Active: active (running) since Tue 2022-02-15 09:41:00 CET; 45min ago
Main PID: 515 (gunicorn)
Tasks: 3 (limit: 2059)
CGroup: /system.slice/lightcontrol.service
├─ 515 /home/pi/controle-des-lumieres-knx/5_Programmation/server/serverenv/bin/python3 └─1231 /home/pi/controle-des-lumieres-knx/5_Programmation/server/serverenv/bin/python3 Si vous avez une erreur à ce niveau, corrigez-la avant de poursuivre la configuration.

Page 17 / 24 - last modified by Forestier Robin on 2022/02/22 08:19

## 8.1.5 - Création du certificat SSL

Vous êtes maintenant avec un serveur http fonctionel grâce à Gunicorn.
Mais le problème reste qu'en terme de sécurité, l'http ne crypte pas les communications.
La preuve, en utilisant WireShark (www.wireshark.org) pour "sniffer" les communication entre mon Pc et le Raspberry (server).
Voici ce que j'ai obtenu:

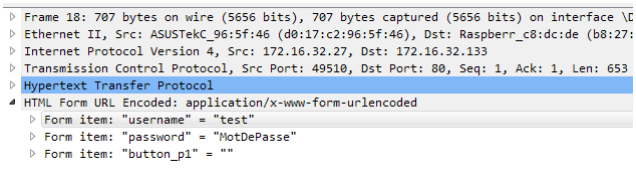
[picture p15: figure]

On peut clairement voir toutes les informations de mon login.
Pour palier à cela, on va passer notre server en HTTPS.
Il nous faudra un "Secure Socket Layer" ou SSL certificate, cela nous permettra de sécuriser toutes les transactions entre le server et le PC.
Normalement, une clé SSL est payante et fonctionne avec un nom de domaine mais travaillant sans nom de domaine, je vais simplement utiliser openssl (https://www.openssl.org).
Commencez par installer nginx.
sudo apt install nginx
Ensuite on va créer le dossier ssl.
sudo mkdir /etc/nginx/ssl/
cd /etc/nginx/ssl/
Puis, on va générer la clef privée RSA:
sudo openssl genrsa -des3 -out server.key 2048
Entrez une phrase (plus longue qu’un simple mot de passe) et répétez-la pour confirmer. Rien ne s’affiche à l’écran lorsque vous tapez. C’est normal.
Après quelques secondes, on obtient le fichier server.key.

Page 18 / 24 - last modified by Forestier Robin on 2022/02/22 08:19

A partir de la clef privée RSA, on va maintenant générer un CSR (Certificate Signing Request). C'est-à-dire un formulaire de demande de certificat.
sudo openssl req -new -key server.key -out server.csr

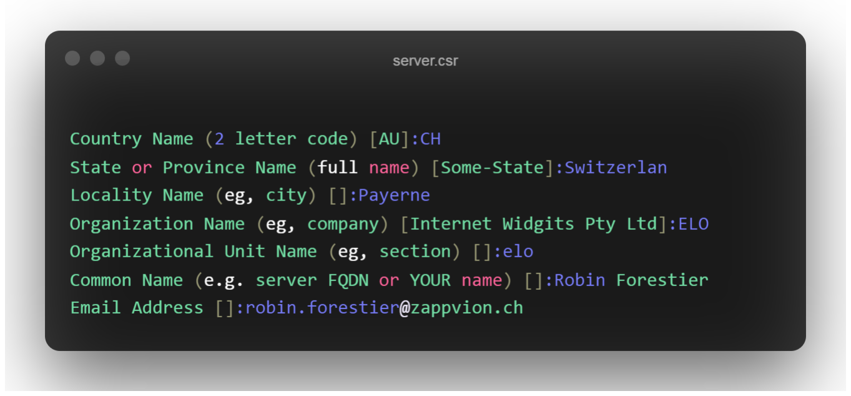
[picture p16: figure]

La seule indication importante est votre nom de domaine "Common Name".
domaine.tld protègera tous les sous-domaines. sousdomaine.domaine.tld ne protègera que le sous domaine mentionné.
Laissez les « extra attributes » vides.
Voilà, la demande de certificat server.csr est créée. Il ne reste plus qu’à la valider. Normalement, c’est une autorité de certification (CA) qui doit signer votre CSR. Elle se porte ainsi garante de l’authenticité des données qui se trouvent dans le certificat. Malheureusement, ce service est souvent payant.
Pour contourner le « problème », nous allons nous ériger en CA et signer nous-même le CSR.
On commence par archiver notre clé privée :
sudo cp server.key server.key.tmp
Puis, on va décrypter la clé privée pour permettre à Nginx de s’en servir sans avoir besoin du mot de passe : sudo openssl rsa -in server.key.tmp -out server.key
On entre la phrase choisie précédemment.
Puis, on signe le CSR avec notre nouvelle clé privée décryptée :
sudo openssl x509 -req -days 1000 -in server.csr -signkey server.key -out server.crt

Page 19 / 24 - last modified by Forestier Robin on 2022/02/22 08:19

## 8.1.6 - Configuration NGINX

On va maintenant configurer Nginx comme proxy pour votre server Gunicorn. sudo nano /etc/nginx/sites-available/lightcontrol
Voici ma configuration :
(ne pas oublier de modifier l'ip)
server {
listen 80;
server_name localhost;
location / {
include proxy_params;
proxy_pass http://unix:/home/pi/controle-des-lumieres-knx/5_Programmation/server/lightcontrol.sock; }
}
server {
listen 80;
server_name 172.16.32.133;
location / {
include proxy_params;
proxy_pass http://unix:/home/pi/controle-des-lumieres-knx/5_Programmation/server/lightcontrol.sock; }
}
server {
listen 443 ssl;
server_name 172.16.32.133;
ssl on;
ssl_certificate /etc/nginx/ssl/server.crt; ssl_certificate_key /etc/nginx/ssl/server.key;
location / {
include proxy_params;
proxy_pass http://unix:/home/pi/controle-des-lumieres-knx/5_Programmation/server/lightcontrol.sock; }
}
On va créer un lien vers sites-enabled.
sudo ln -s /etc/nginx/sites-available/lightcontrol /etc/nginx/sites-enabled Avec ce lien, vous pouvez verifier s'il n'y a pas d'erreur de syntax.
sudo nginx -t
Si ça ne vous renvoie aucune erreur, vous pouvez redémarrer nginx.
sudo systemctl restart nginx
Vous pouvez maintenant taper l'ip de votre Raspberry dans la barre de recherche de votre navigateur et votre site devrait apparaitre.
Si une page avec marqué "Welcome to nginx!" apparaît, il vous faudra encore supprimer le fichier index de nginx. sudo rm /var/www/html/index.nginx-debian.html

Page 20 / 24 - last modified by Forestier Robin on 2022/02/22 08:19

## 8.1.7 - Lancement Navigateur

Et vous avez presque fini. Il faut encore que votre navigateur se lance automatiquement au démarrage. Pour cela, modifiez le fichier autostart :
sudo nano /etc/xdg/lxsession/LXDE-pi/autostart
Et rajoutez cette ligne en indiquant l'ip du Raspberry Pi.
@chromium --kiosk http://172.16.32.133
Vous pouvez ensuite redémarrer votre Raspberry et tout est normalement fonctionel.

## 9.0 - Sauvgarde de l'image

Si vous réalisez des modifications importantes sur le Raspberry (autres que dans le fichier sur le git).
Vous devriez sauvgarder votre version de votre image sur le OMVSERVER.
Pour cela, il vous faudra le logiciel Win32 Disk Imager.
Banchez la carte SD sur votre PC. Dans l'interface indiquez l'emplacement où ira se stocker votre image et son nom.
Sélectionnez le périférique, puis cliquez sur "Lire". Il faudra attendre que la copie se face, puis votre image sera copiée.

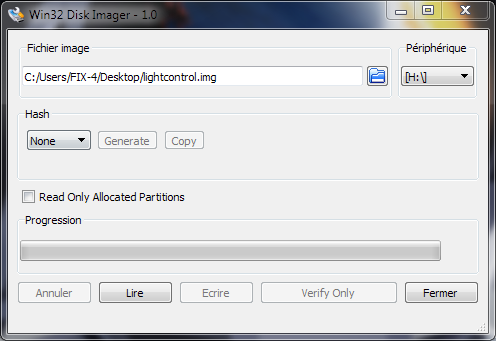
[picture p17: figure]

ref: OMVSERVER\formation\Projets\ControleDesLumiersKNX\lightcontrol.img

Page 21 / 24 - last modified by Forestier Robin on 2022/02/22 08:19

# 9.0 - Câblage

Pour le cablage, il faut brancher l'alimentation de l'écran sur le connecteur Wago X4 à gauche de la carte. Les US/U 4.2 se branchent dans les connecteurs X1 - X3. Chaque connecteur comporte 5 pôles.
COM | DRV1 | DRV2 | DRV3 | DRV4
Les connecteurs sont connecté aux GPIO suivants:
Connecteur | GPIO
X1 | 0 - 3
X2 | 4 - 7
X3 | 8 - 11

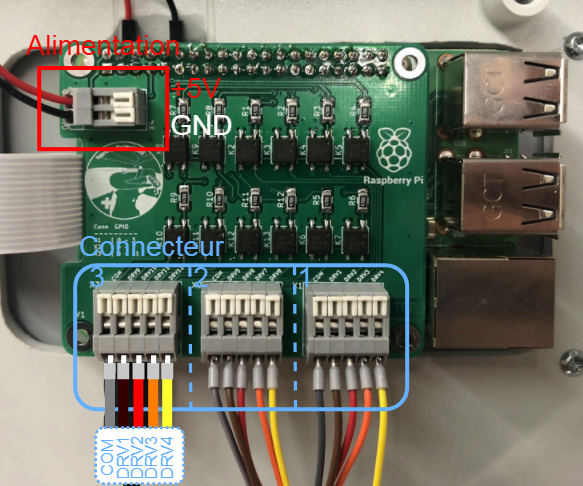
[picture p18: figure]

Page 22 / 24 - last modified by Forestier Robin on 2022/02/22 08:19

# 10.0 - Mécanique

Pour placer l'écran sur la porte du boîtier Fibox, j'ai percé 4 trous et réalisé une fenêtre carrée pour que le Raspberry puisse y passer.
ref: /1_Documentation/7-inch-display-mechanical-drawing.pdf & /1_Documentation/raspberry-pi-3-b-plus-mechanical-drawing.pdf on GitLab.

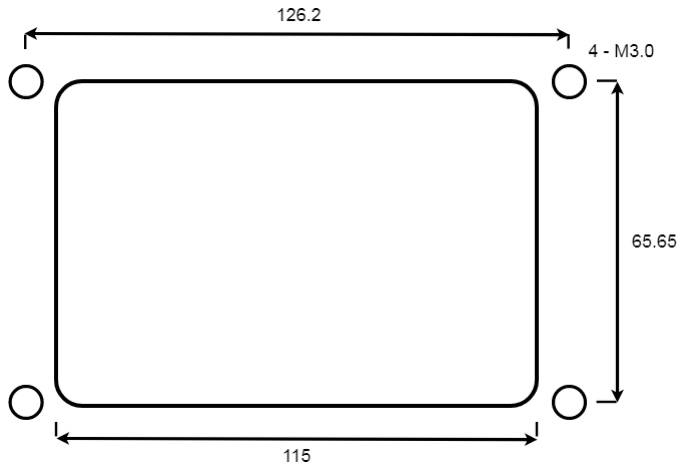
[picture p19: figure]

Page 23 / 24 - last modified by Forestier Robin on 2022/02/22 08:19

## 10.1 - Fixation

Pour la fixation à l'interrieur du boîtier, j'ai utilisé trois rails DIN 35mm.
Sur le premier rail, j'ai placé les trois US/U 4.2 et l'allimentation 5V (TBLC 25-105) pour le Raspberry Pi. Le deuxième rail sera utilisé par les électriciens.
Sur le troisième rail, il y a les deux boîtiers SA/S 4.16.2.2.

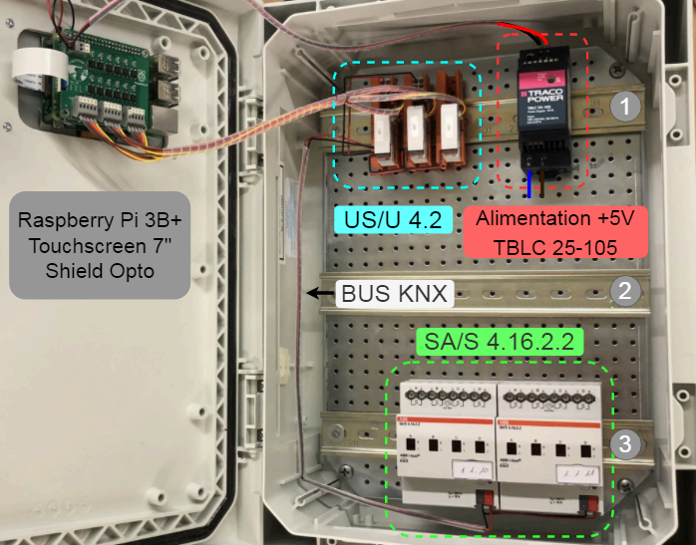
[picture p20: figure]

Page 24 / 24 - last modified by Forestier Robin on 2022/02/22 08:19

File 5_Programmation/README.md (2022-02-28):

# 5_Programmation #

Vous trouverez ici toutes les version de l'interfaces utilis�e pour ce projet.

## versions ##

1. interface_test

interface de base avec TKinter
version GPIO controle les gpio du raspberry.

2. interface_2_plan

Interface avec tkinter ajoutant du graphisme.

3. Interface_HTML

interface flask créant un site WEB.

4. Server

Dernière version du server.

## server ##

Dossier server stoque la version que le serveur utilise.
Nommer le fichier main.py
Le fichier wsgi.py serra executer automatiquement aux lancement si NGINX est correctement
configuré.

Le fichier config.csv contient les configuration pour l'auto on / off.

Le fichier log.log contient les log de l'application.

Le dossier doc contient la doc du code.
## ##
    
<div align="center">
    <i>Robin Forestier</i>
</div>

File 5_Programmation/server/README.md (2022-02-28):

# Elo light control #

## But : ##

Le but de ce project est de controller les lumières de l'atelier avec un interface graphique sur l'écran tactile du Raspberry Pi 3B+.

## Requirement ##

pip install -U -r requirements.txt

## Test ##

./test/flask_test.py

Lancer ce fichier pour tester le serveur flask.

## Doc ##

./doc/

main.html

Fichier contenant la doc du code auto générée par [Pdoc3](https://pypi.org/project/pdoc3/).

### Pdoc3 ###

```
pip install pdoc3
pdoc -o doc --html main.py
```

ou

```
pdoc -o doc --html main.py --force
```

## launching the app ##

sudo python3 main.py

/!\ sudo est utilisé (sur linux) pour authoriser l'utilisaton du port 80.

Pour utiliser le server complétement référez vous aux XWiki.

## Liens ##

[Gitlab](http://172.16.32.230/Forestier/controle-des-lumieres-knx)

[XWiki](https://xwiki.serverelo.org/xwiki/bin/view/Centre%20de%20Formation%20ELO/Projets/Controle%20des%20lumières%20KNX/)

## ##

Robin Forestier 2021 / 2022

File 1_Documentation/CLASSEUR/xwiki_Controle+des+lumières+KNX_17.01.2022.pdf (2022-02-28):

# Controle des lumières KNX

last modified by Forestier Robin
on 2022/01/17 09:26

Projets - Controle des lumières KNX

- 1.0 - But
- 2.0 - Liens
- 3.0 - Composants
- 4.0 - Schéma Bloc
- 5.0 - Shield Opto
- 5.1 - Shéma Shield Opto
- 5.2 - PCB Shield Opto
- 6.0 - GUI
- 6.1 - Utilisateurs
- 6.2 - Pages
- 6.2.1 - Login
- 6.2.2 - page1
- 6.2.3 page 2
- 6.2.4 - Settings
- 6.2.5 - téléphone
- 7.0 - Programmation
- 7.1 - Code Python
- 7.1.1 - Config
- 7.2 - HTML
- 7.3 - CSS
- 8.0 - Instalation du raspberry
- 8.1 - Instalation
- 8.1.1 - Image
- 8.1.2 - Git clone
- 8.1.3 - NGINX
- 8.1.4 - Configuartion du server
- 8.1.5 - Configuration du Proxy NGINX
- 8.1.6 - SSL certificat
- 8.1.6.1 - Configuartion du Certificat SSL
- 8.1.7 - Sauvgarde de l'image
- 9.0 - Câblage
- 10.0 - Mécanique

Page 2 / 27 - last modified by Forestier Robin on 2022/01/17 09:26

# 1.0 - But

Le but de ce project est de réaliser une interface graphique pour le controle des lumières de l'atelier. L'écran est un Raspberry Pi 7" Touchscreen Display controlé par un raspberry Pi 3B+.
Une interface à l'aide d'optocoupleur est utilisée et directement controllé par les GPIO du raspberry. Pour le controle des lumière, nous utilisons deux module, un US/U 4.2 de ABB et un SA/S 4.16.2.2.

# 2.0 - Liens

Gitlab (http://http://172.16.32.230/Forestier/controle-des-lumieres-knx)
ABB - US/U 4.2 (https://new.abb.com/products/fr/GHQ6310070R0111/us-u4-2)
ABB - SA/S 4.16.2.2 (https://new.abb.com/products/fr/2CDG110262R0011/sa-s4-16-2-2)
Explication KNX (http://www.knx-fr.com/showthread.php?tid=2129)

# 3.0 - Composants

Pour le project :
Nom | Nombre | Prix unité | Prix tolal
Raspberry Pi 3B+ | 1 | 40.90 | 40.90
Raspberry Pi 7" Touchscreen 1 | 74.90 | 74.90
US/U 4.2 | 3 | 83.80 | 251.40
SA/S 4.16.2.2 | 2 | 169.60 | 339.20
Fibox ARCA 403015 | 1 | 96.90 | 96.90
Total | | | 803.30
Pour la carte Shield Opto :
Reference | Value | Prix unité | Prix total
K2-K13 | ASSR-1218 | 1.75 | 21
x1-x3 | WAGO 218-505 | 3.25 | 9.75
x4 | WAGO 218-502 | 1.55 | 1.55
Total | | | 32.30

Page 3 / 27 - last modified by Forestier Robin on 2022/01/17 09:26

# 4.0 - Schéma Bloc


Comme on peut le voir sur ce shéma block, on utilise plusieurs système de communication. Les Gpio du Raspberry control directement le shiel octo puis les US/U 4.2.
Les SU/U 4.2 communique avec les SA/S en KNX (www.knx.ch).
Et les autre appareil communique en TCP via le wifi.

Page 4 / 27 - last modified by Forestier Robin on 2022/01/17 09:26

# 5.0 - Shield Opto

Pour controller les modul US/U 4.2 de chez ABB, nous utilisons des Optocoupleur mosfet contrôler par les GPIO du raspberry. J'ai donc réaliser le shield opto qui vient directement se brancher sur le raspberry pour faciliter le cablâge et minimiser l'espace.

## 5.1 - Shéma Shield Opto


Page 5 / 27 - last modified by Forestier Robin on 2022/01/17 09:26

## 5.2 - PCB Shield Opto


# 6.0 - GUI

Pour la partie graphique, j'ai tout d'abord essayer avec la librairie Python TKinter. https://docs.python.org/fr/3/library/tkinter.html
Les version de test se trouve sur sur le gitlab sous 5_Programmation.
Mais pour symplifier le tout et pouvoir dans le futur ajouter une partie résaux à ce project, j'ai donc choisi d'héberger un site web. En utilisant Flask sur Python, je peux donc facilement héberger le site sur mon raspberry pi et me connecter dessu simplement en connaissant l'adresse IP.

## 6.1 - Utilisateurs

Pour assurer la securité du site, il existe 3 utilisateur différent.
1: elo
L'utilisateur elo peut, s'il connait le mot de passe, allumer ou éteindre les lumières sans pouvoir accéder aux paramètres.
2: admin
L'utilisateur admin a tous les accès.
3: local
L'utilisateur local n'as pas besoin de se connecter pour accéder aux site, son authentification se fait à l'aide de son IP. Il ne peut pas accéder aux réglage de l'application.

Page 6 / 27 - last modified by Forestier Robin on 2022/01/17 09:26

## 6.2 - Pages

Le site est constituer de 4 pages distinctes.
6.2.1 - Login
La page de login permet de se connecter via un périférique autre que l'écran tactile.

6.2.2 - page1
La page 1 contient à gauche un plan de l'atelier qui se modifie selon les lumières allumées.
A droite 9 boutons permettes d'allumer séparément chaque rail de lumières. Le bouton en bas à droite permet de se rendre sur la page 2.
Le logo ELO en haut à droite permet d'accéder aux réglage (admin only).

Page 7 / 27 - last modified by Forestier Robin on 2022/01/17 09:26

### 6.2.3 page 2

La page 2 est une copie de la page 1 avec comme modification l'action des boutons de droites. On y retrouve:
- All ON | tout allumer
- ALL OFF | tout éteindre
- 1/2 | allumer 1 sur 2
- D | allumer la droite de l'atelier
- G | allumer la gauche de l'atelier
- N/C | non connecter (réserver pour usage future)

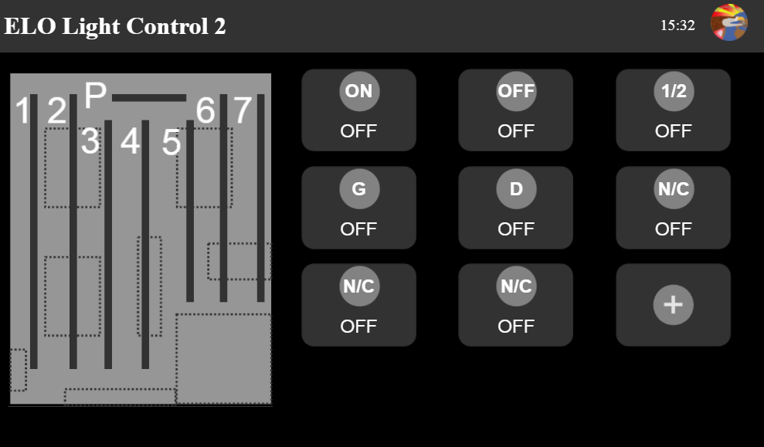
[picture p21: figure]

6.2.4 - Settings
La page settings accessible uniquement par le compte admin permetra de régler les paramètre important. 6.2.5 - téléphone
J'au aussi réaliser une mise en page pour téléphone.

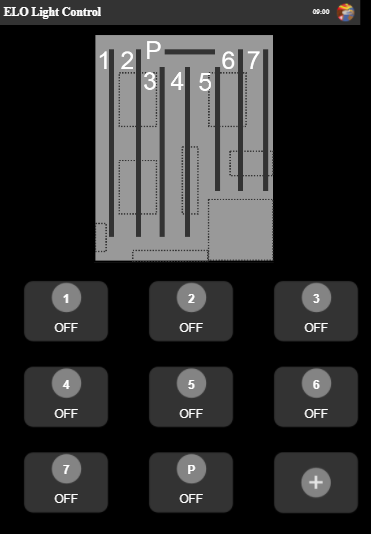
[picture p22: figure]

Page 8 / 27 - last modified by Forestier Robin on 2022/01/17 09:26

# 7.0 - Programmation

Pour la programmation de cette interface j'ai utilisé python. Plus précisément flask. https://flask.palletsprojects.com
Flask est un micro framework open-source de développement web en Python. (Wikipedia)
Avec flask je peux facilement héberger un server web. Il suffit de créer les fichier: static & templates. \5_Programmation
│
└──INT_SERV
│
├──static
│ │
│ └──img
│
└──templates
Le programme python se trouve dans le dossier principal (INT_SERV). Les ficher HTML se trouvent dans templates.
Les fichier CSS se trouvent dans static.
Les images se trouves dans static\img.
On retrouve aussi le fichier config.csv dans le dossier principal.

## 7.1 - Code Python

Pour ce code j'ai besoi de ces bibliothèques.

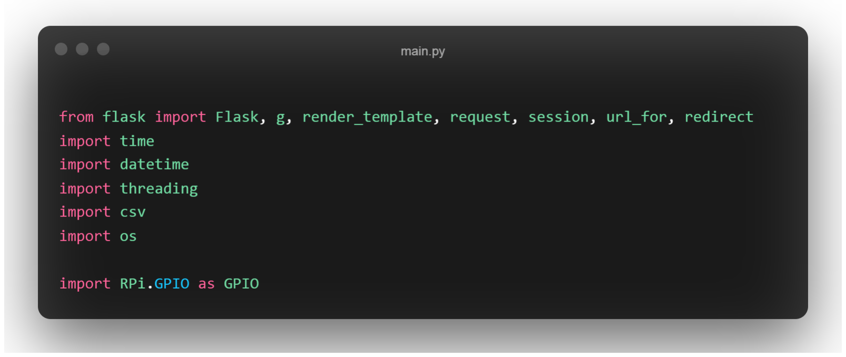
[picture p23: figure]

Quand on viens se connecter avec le raspberry sur le site web on ne veut pas qu'il aie à ce loger. Pour le loger automatiquement, j'ai créer une liste des IP autorisées.

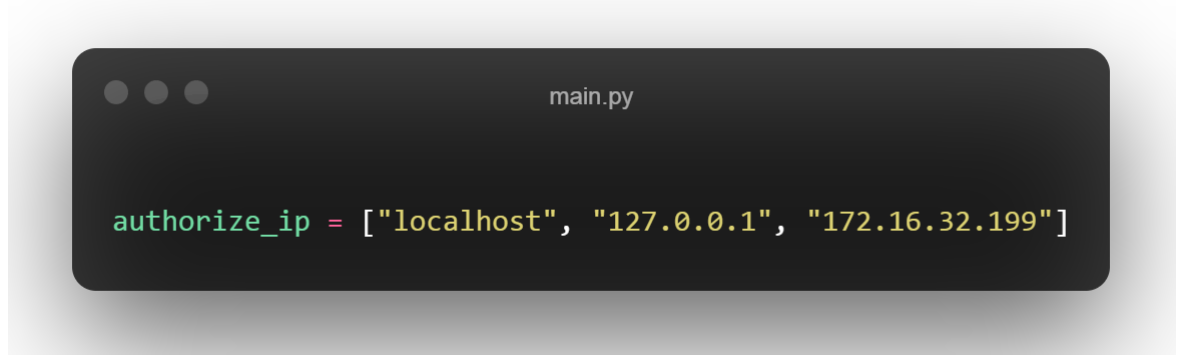
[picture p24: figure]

Page 9 / 27 - last modified by Forestier Robin on 2022/01/17 09:26

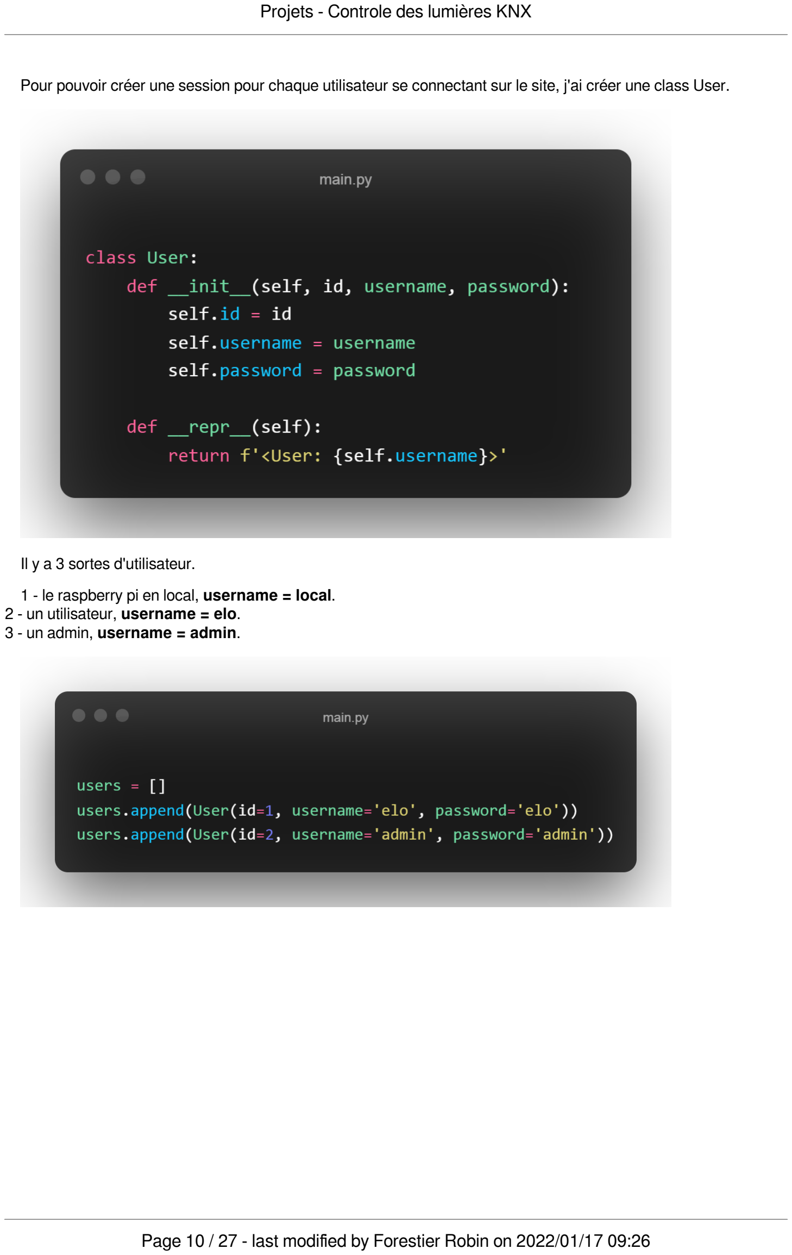
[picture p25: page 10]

Pour pouvoir créer une session pour chaque utilisateur se connectant sur le site, j'ai créer une class User.

Il y a 3 sortes d'utilisateur.
1 - le raspberry pi en local, username = local. 2 - un utilisateur, username = elo.
3 - un admin, username = admin.

Page 10 / 27 - last modified by Forestier Robin on 2022/01/17 09:26

Une fonction before_request() et automatiquement appelée quand un utilisateur arrive sur le site. Cette fonction viens verifier si l'utilisateur et déjà enregistrer ou pas pour lui afficher la page login ou non. C'est aussi là qu'est créer l'utilisateur local.


Page 11 / 27 - last modified by Forestier Robin on 2022/01/17 09:26


Chaque page web a sa propre fonction pour pouvoir interagire avec les request. Dans l'ordre, login, page1, page2 et settings.

Pour que l'utilisateur puisse voir quelque chose, il faut lui retourner la page.
On va donc return le fichier HTML correspondant à l'aide de la fonction render_template(). On ajoute aussi toutes les variable qui serront affichées sur la page come l'heur (time).

Page 12 / 27 - last modified by Forestier Robin on 2022/01/17 09:26

Une dernière fonction est la fonction activate_job().
Cette fonction s'execute aux moment ou la première personne essaie de se connecter aux site.
Un thread et créer pour réaliser toutes les autres activité comme: les automatisations ou le warning de température.


Et pour finir le main.


7.1.1 - Config
Le fichier config.csv contient les information pour la page settings.
Ces information sont stoquée en externe du programme pour assurer quelle soit sauvgardée même aprèt un redémarage.
Pour le moment les seul information stoquées sont.
Auto on et Auto off; ce qui correspond à l'allumage automatique des lumière à un certaine heur.
Voici son contenu :

Page 13 / 27 - last modified by Forestier Robin on 2022/01/17 09:26

## 7.2 - HTML

Les fichiers HTML se trouvent sous \5_programmation\nom_de_version\templates On retrouve évidement un fichier HTML par page.
Détaillons le fichier page1.html.
Premièrement, j'utilise une balise meta pour venir reload automatiquement ma page. Cesi permet, en cas de modification d'un autre utilisateur, d'afficher ses dites modification.

Dans le header, on peut voir l'heur affichée a gauche.
Pour le faire, dans mon code python, je viens ajouter time quand j'appelle la fonction render_template(). Et pour l'afficher sur ma page web, il suffit d'écrire { {time} }


Page 14 / 27 - last modified by Forestier Robin on 2022/01/17 09:26

Viens ensuite le plan de l'atelier. Ce plan est une image où je viens simplement dessiner les néon allumer. Le script récupère la couleur des différent néon et créer un rectangle à la bonne place.


Page 15 / 27 - last modified by Forestier Robin on 2022/01/17 09:26

Pour finir, il reste à afficher les bouttons.
Pour cela j'ai réaliser une boucle for.
Il faut utiliser Jinja: https://jinja.palletsprojects.com/en/3.0.x/templates/
Puis on créer le dernier bouton pour accéder à la page suivante.
Il faut aussi créer deux faut text pour qu'il agisse correctement avec les règle css.


Page 16 / 27 - last modified by Forestier Robin on 2022/01/17 09:26

## 7.3 - CSS


Les fichiers CSS se trouvent dans \5_programmation\nom_de_version\static. Il y a 3 fichier css.
style.css - utilisé pour les pages: page1 et page2.
login.css - utilisé pour la page: login.
settings.css - utilisé pour la page: settings.
Il y quelques points importants que je vais expliquer ci-dessous.
Pour l'affichage du plan a côté des boutons, j'utilise deux colonne (l et r).

Puis pour afficher les 9 boutons, j'utilise une grille.

Page 17 / 27 - last modified by Forestier Robin on 2022/01/17 09:26

Pour avoir un meilleur affichage sur l'écran du raspberry, j'ai créer une partie du css exprèt.

Et j'au aussi créer un partie pour les téléphone portable.


Page 18 / 27 - last modified by Forestier Robin on 2022/01/17 09:26

# 8.0 - Instalation du raspberry

Pour l'installation du raspberry il vous suffit de récupérer cette image :
ref: OMVSERVER\formation\Projets\ControleDesLumiersKNX\lightcontrol.img et de la flasher sur une carte SD.
Vous pourrez ensuite pull la dernière version du gitlab.
Tout et prêt a fonctionner

## 8.1 - Instalation

Pour réaliser une instalation complète suivez ces étapes. 8.1.1 - Image
Pour faire fonctionner votre raspberry, il vous faudra une image. Vous pouvez simplement télécharger Raspberry Pi Imager. https://www.raspberrypi.com/software/
Installer l'OS de votre choix sur une carte SD.
Configuré votre Raspberry.
vous pouvez installer Xscreen saver pour désactiver la mise en veille. sudo apt-get install xscreensaver
Puis dans l'app, choisir désactiver la mise en veille.
Vous pouvez aussi activer VNC et le SSH pour vous faciliter la vie. Pour utiliser les GPIO correctement vous devez :
sudo raspi-config
8.1.2 - Git clone
Pour cloner le gitlab copier cette commande dans votre terminal. (vérifier s'il n'a pas été déplacer sous Projets_Ancien_Apprentis)
git clone http://172.16.32.230/Forestier/controle-des-lumieres-knx
8.1.3 - NGINX
Vous pouvez tester le server en exécutant le main.py dans le dossier server.
cd controle-des-lumieres-knx/5_Programmation/server
sudo python3 main.py
Pour que le server WEB se lance automatiquement aux lancement du Raspberry Pi et pour que le server se soit plus un serveur de développement,
J'ai choisi d'utiliser un server NGINX, il peut aussi servire de proxy mais je n'est pas souhaiter aller aussi loin dans ce dévellopement.
Pour l'installation vous pouvez suivre ce tuto : https://www.digitalocean.com/community/tutorials/how-to-serve-flask-applications-with-gunicorn-and-nginx-on-ubuntu-18-04 (https://www.digitalocean.com/community/tutorials/how-to-serve-flask-applications-with-gunicorn-and-nginx-on-ubuntu-18-04) (/1_Documentation/Flask_server_Gunicorn_DigitalOcean.pdf)
Ou sinon lire la suite.
Premièrement dans ce tuto ils créent un environement virtuel. Si vous avez cloné le GitLab alors il existe déjà. source serverenv/bin/activate
Vous devez ensuite vérifier si le fichier wsgi.py existe.

Page 19 / 27 - last modified by Forestier Robin on 2022/01/17 09:26


Sinon créer le.

Utiliser la commande suivante pour lancer votre server avec uWsgi: gunicorn bind 0.0.0.0:5000 wsgi:app
Vous pouvez maintenant sortir de l'environement virtuel. deactivate
8.1.4 - Configuartion du server
Pour le configuré :
sudo nano /etc/systemd/system/lightcontrol.service

Now start the Gunicorn service you created: sudo systemctl start lightcontrol
Then enable it so that it starts at boot:

Page 20 / 27 - last modified by Forestier Robin on 2022/01/17 09:26 sudo systemctl enable lightcontrol Check the status:
sudo systemctl status lightcontrol
Vous devez voir:
Active: active (running)
si ce n'est pas le cas re vérifier les fichiers précédent.
Et vous avez presque fini. Il faut encore que votre navigateur se lance automatiquement aux démarage. Pour cela il faut rajouter cette ligne:
@chromium kiosk http://localhost
Dans le fichier:
sudo nano /etc/xdg/lxsession/LXDE-pi/autostart
Chromium se lancera automatiquement en mode pleine écran et vous connectera sur votre site web (localhost). Avec cette simple instalation vous n'avez pas de proxy et pas de sécurisation de vos packets.
8.1.5 - Configuration du Proxy NGINX
On va maintenant mettre en place le proxy NGINX.
On commence par créer un fichier de configuration.
sudo nano /etc/nginx/sites-available/lightcontrol
Voila comment il doit être rempli pour que toutes les requets vers l'ip du raspberry soit reçue et traitée par le serveur.


Page 21 / 27 - last modified by Forestier Robin on 2022/01/17 09:26

Pour autoriser, il faut créer un lien vers le répertoire "sites-enabled". sudo ln -s /etc/nginx/sites-available/myproject /etc/nginx/sites-enabled Maintenant vous pouvez verifier si il n'y a pas d'erreur de syntaxe. sudo nginx -t
Si il n'y a pas d'erreur, vous pouvez relancer NGINX.
sudo systemctl restart nginx
Votre site web avec proxy est prêt.
8.1.6 - SSL certificat
Vous êtes maintenant avec un serveur http fonctionelle.
Mais le problème reste qu'en terme de sécurité, l'http ne crypte pas les communication.
La preuve, j'ai utilisé WireShark (www.wireshark.org) pour snifer les communication entre mon Pc et le Raspberry (server).
Voici ce que j'ai obtenu:


On peut clairement voir toutes les informations de mon login.
Pour palier à cela, on va passer notre server en HTTPS.
Il nous faudra un "Secure Socket Layer" ou SSL certificate, Il permet de sécuriser tous les transaction entre le server et le PC.
Normalement une clé SSL est payante et fonctionne avec un nom de domaine mais travaillant sans nom de domaine, je vais simplement utiliser openssl (https://www.openssl.org).
8.1.6.1 - Configuartion du Certificat SSL
On commence par créer un dossier dans lequel on va placer les clefs.
sudo mkdir /etc/nginx/ssl/
cd /etc/nginx/ssl/
Puis, on va générer la clef privée RSA:
sudo openssl genrsa -des3 -out server.key 2048
Entrez une phrase (plus longue qu’un simple mot de passe) et répétez-là pour confirmer.
Rien ne s’affiche à l’écran lorsque vous tapez. C’est normal.
Après quelques secondes, on obtient le fichier server.key.
A partir de la clef privée RSA, on va maintenant générer un CSR (Certificate Signing Request). C-à-d un formulaire de demande de certificat.
sudo openssl req -new -key server.key -out server.csr

Page 22 / 27 - last modified by Forestier Robin on 2022/01/17 09:26


La seule indication importante est votre nom de domaine « Common Name« .
domaine.tld protègera tous les sous-domaines. sousdomaine.domaine.tld ne protègera que le sous domaine mentionné.
Laissez les « extra attributes » vides.
Voilà, la demande de certificat server.csr est créée. Il ne reste plus qu’à la valider. Normalement, c’est une autorité de certification (CA) qui doit signer votre CSR. Elle se porte ainsi garante de l’authenticité des données qui se trouvent dans le certificat. Malheureusement, ce service est souvent payant.
Pour contourner le « problème », nous allons nous ériger en CA et signer nous même le CSR.
On commence par archiver notre clef privée :
sudo cp server.key server.key.tmp
Puis, on va décrypter la clef privée pour permettre à Nginx de s’en servir sans avoir besoin du mot de passe : sudo openssl rsa -in server.key.tmp -out server.key
On entre la phrase choisie précédemment.
Puis, on signe le CSR avec notre nouvelle clef privée décryptée :
sudo openssl x509 -req -days 1000 -in server.csr -signkey server.key -out server.crt
Il ne reste plus qu'a ajouter la configuration pour le port 443 et le ssl dans le fichier lightcontrol. sudo nano /etc/nginx/sites-available/lightcontrol

Page 23 / 27 - last modified by Forestier Robin on 2022/01/17 09:26

sudo nginx -t
sudo systemctl restart nginx
Et c'est fini, vous avez enfin complétement configuré votre serveur.

Page 24 / 27 - last modified by Forestier Robin on 2022/01/17 09:26

8.1.7 - Sauvgarde de l'image
Il ne vous reste plus qu'à savgarder l'image de votre raspberry. Pour cela il vous faudra le logiciel Win32 Disk Imager.
Bancher la carte SD sur votre PC. Dans L'interface indiquer l'emplacement ou ira se stocker votre image et son nom.
Sélectionner le périférique, puis cliquer sur Lire. Il faudra attendre que la copie se face puis votre image serra copiée.


ref: OMVSERVER\formation\Projets\ControleDesLumiersKNX\lightcontrol.img

Page 25 / 27 - last modified by Forestier Robin on 2022/01/17 09:26

# 9.0 - Câblage

Pour le cablage, il faut brancher l'alimentation de l'écran sur le connecteur Wago X4 à gauche de la carte. Les US/U 4.2 se branche dans les connecteurs X1 - X3. Chaque connecteur comporte 5 pôles.
COM | DRV1 | DRV2 | DRV3 | DRV4
Les connecteurs sont connecter aux GPIO suivant :
Connecteur | GPIO
X1 | 0 - 3
X2 | 4 - 7
X3 | 8 - 11


Page 26 / 27 - last modified by Forestier Robin on 2022/01/17 09:26

# 10.0 - Mécanique

Pour placer l'écran sur la porte du boitier Fibox, j'ai percer 4 trous et réaliser une fenêtre carrée pour que le raspberry puisse y passer.
ref: /1_Documentation/7-inch-display-mechanical-drawing.pdf & /1_Documentation/raspberry-pi-3-b-plus-mechanical-drawing.pdf on GitLab.


Page 27 / 27 - last modified by Forestier Robin on 2022/01/17 09:26

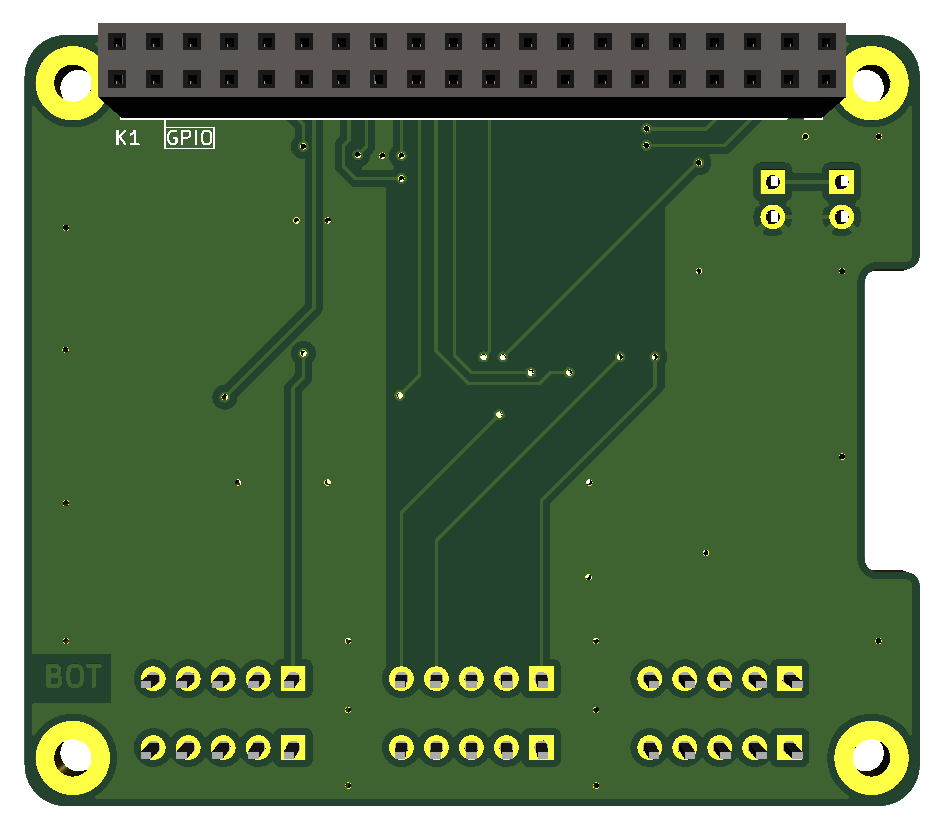
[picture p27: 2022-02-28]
1_Documentation/IMG_WIKI/DOC_FAB/GERBER_3D_BOT.PNG

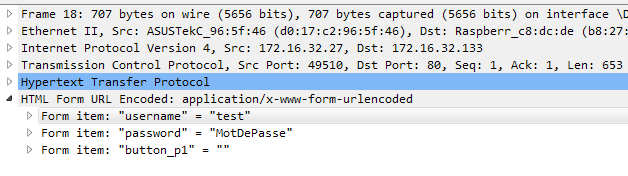
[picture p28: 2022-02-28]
1_Documentation/IMG_WIKI/wireshark_http.PNG

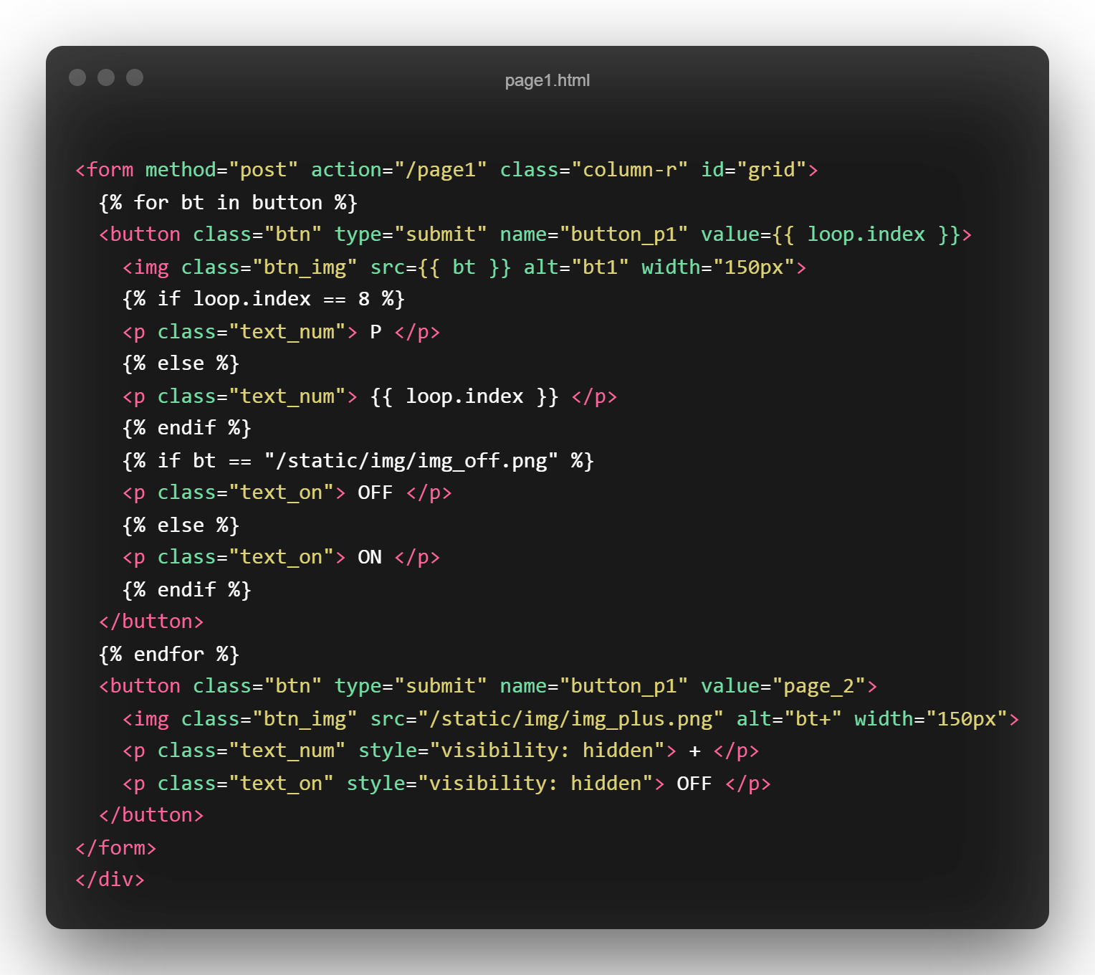
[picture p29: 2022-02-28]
1_Documentation/IMG_WIKI/IMG_CODE/html/html_button.png

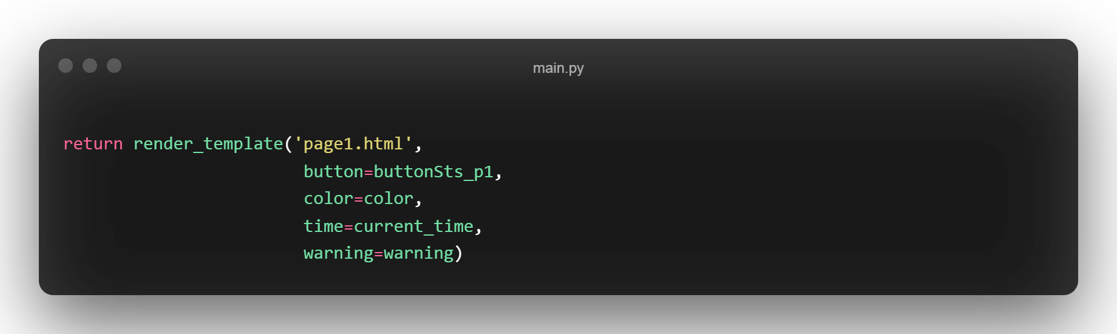
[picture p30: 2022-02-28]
1_Documentation/IMG_WIKI/IMG_CODE/python/code_return.png

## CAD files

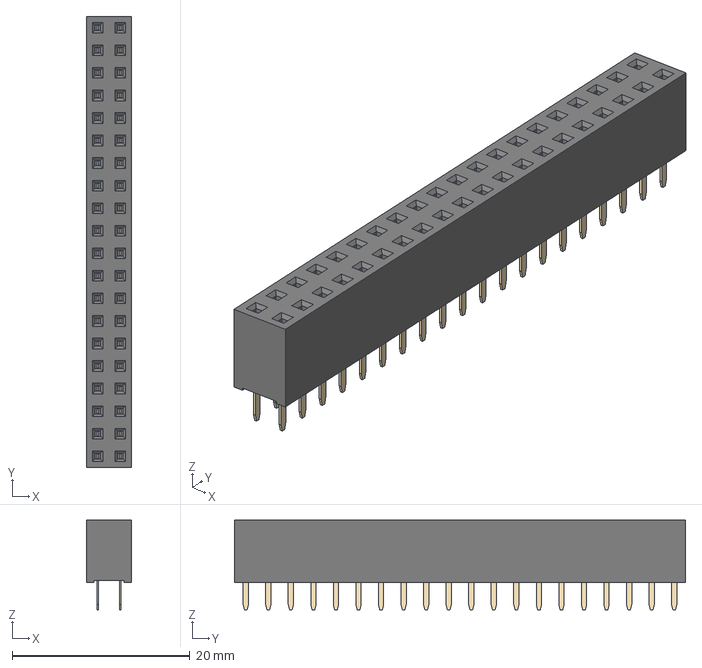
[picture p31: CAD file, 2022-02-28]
4_Fabrication/Version_1/C_Kicad/shield_octo/shapes3D/PinSocket_2x20_P2.54mm_Vertical.step
5.08 x 50.8 x 10.1 mm

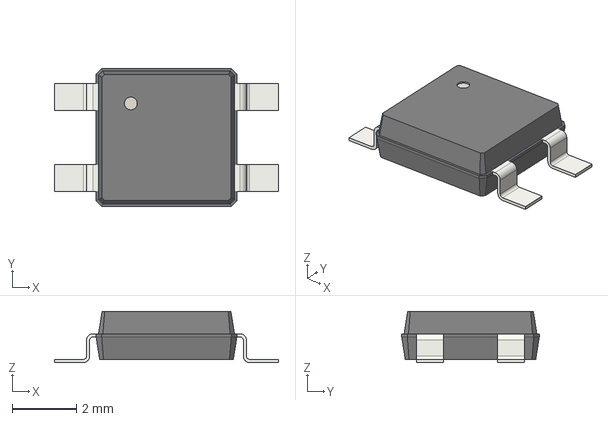
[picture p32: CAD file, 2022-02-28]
4_Fabrication/Version_1/C_Kicad/shield_octo/shapes3D/SO-4_4.4x4.3mm_P2.54mm.step
7.00 x 4.30 x 1.60 mm

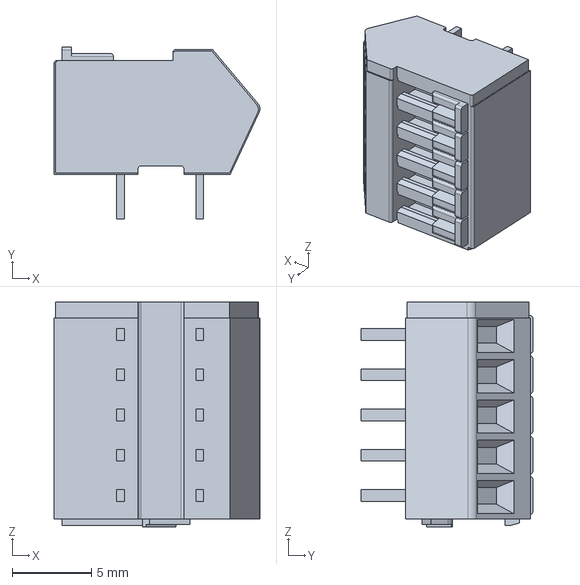
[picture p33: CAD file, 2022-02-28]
4_Fabrication/Version_1/C_Kicad/shield_octo/shapes3D/218-505.stp
13.0 x 10.9 x 14.2 mm

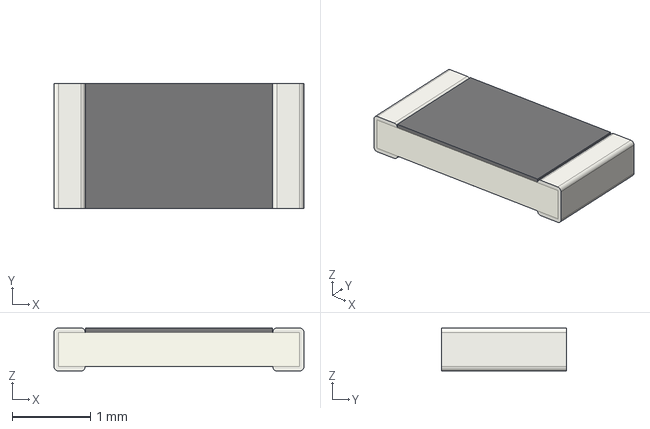
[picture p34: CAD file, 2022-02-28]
4_Fabrication/Version_1/C_Kicad/shield_octo/shapes3D/R_1206_3216Metric.step
3.20 x 1.60 x 0.55 mm

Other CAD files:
4_Fabrication/Version_1/C_Kicad/shield_octo/shapes3D/218-502_MOR.stp

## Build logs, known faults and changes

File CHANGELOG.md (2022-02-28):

# Changelog #

2021 / 2022  Robin Forestier

All notable changes to this project will be in this file.

## 22.02.2022 ##

Create the API doc with Pdoc3.

## 15.02.2022 - New version of the doc ##

New version of the XWiki [LINK](https://xwiki.serverelo.org/xwiki/bin/view/Centre%20de%20Formation%20ELO/Projets/Controle%20des%20lumières%20KNX/)

I have create a new Image of the RPI 
(\\OMVSERVER\formation\Projets\ControleDesLumiersKNX\lightcontrol_15_02_2022.img)

## 14.02.2022 - Change the session / add database ##

I hade a database (sqlite3) for saving the session id.
This is more secure and avoid the creation of multiple "fake" user.

## 07.02.2022 - Add error page ##

Add error handler on the main.py 
Add 404.html and 404.css

Add flash error on the login page.

## 01.02.2022 - modification on Wiki ##

Update of the XWiki.

## 31.01.2022 - css for phone ##

Modif all thze css for phone size.

## 26.01.2022 - new css ##

Change all button on css.
add the new login page to server.
change server file.

## 25.01.2022 - Login page ##

Redisigne all the login page.

## 17.01.2022 - Add all doc ##

Create a folder with all the doc to print for the workbook.
Add the oldest version of the wiki on pdf.

## 11.01.2022 - Image / Doc ##

Adding a copie of my Raspberry Pi image. (/lightcontrol.img)
Finish doc on XWiki

## 10.01.2022 - Bug Fix ##

Fixe all bugs, app working properly.
Auto start ok.
visualisation ok.
V1 complete.

## 10.01.2022 - Create Changelog ##

Creat first version of the Changelog file

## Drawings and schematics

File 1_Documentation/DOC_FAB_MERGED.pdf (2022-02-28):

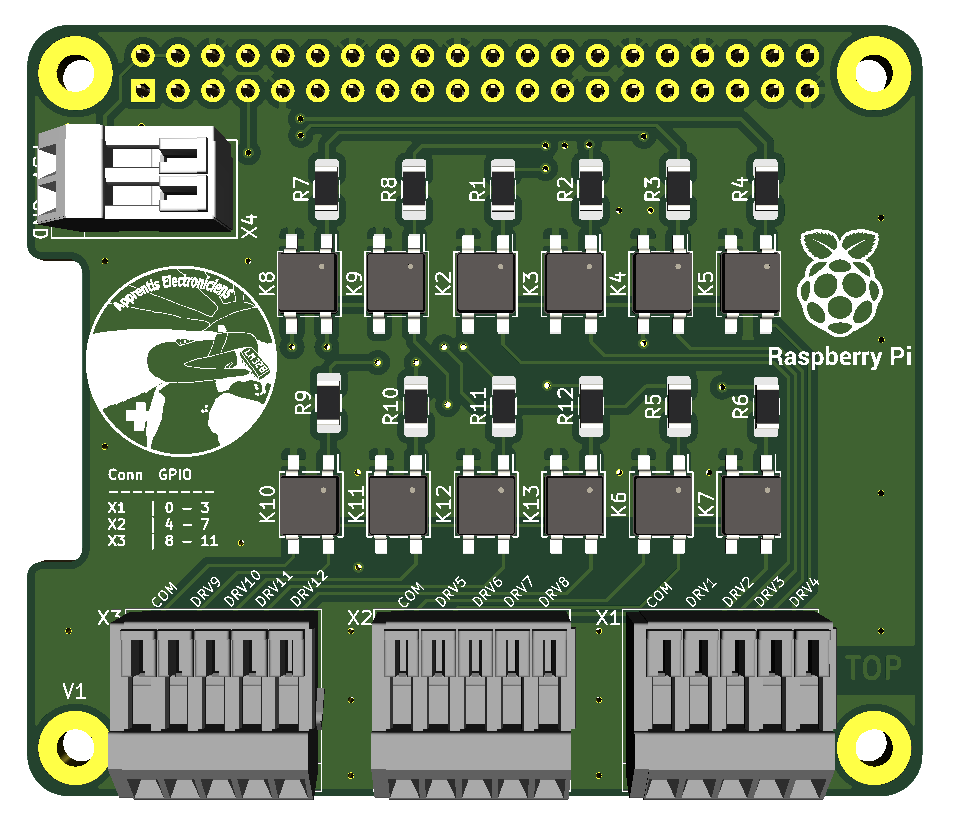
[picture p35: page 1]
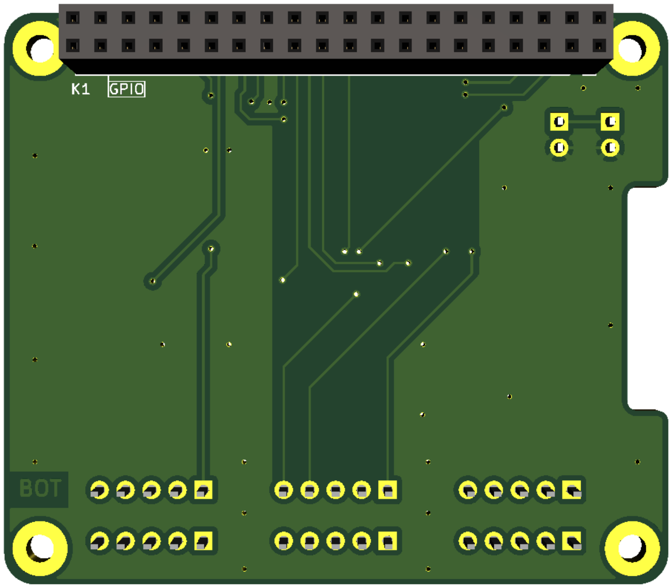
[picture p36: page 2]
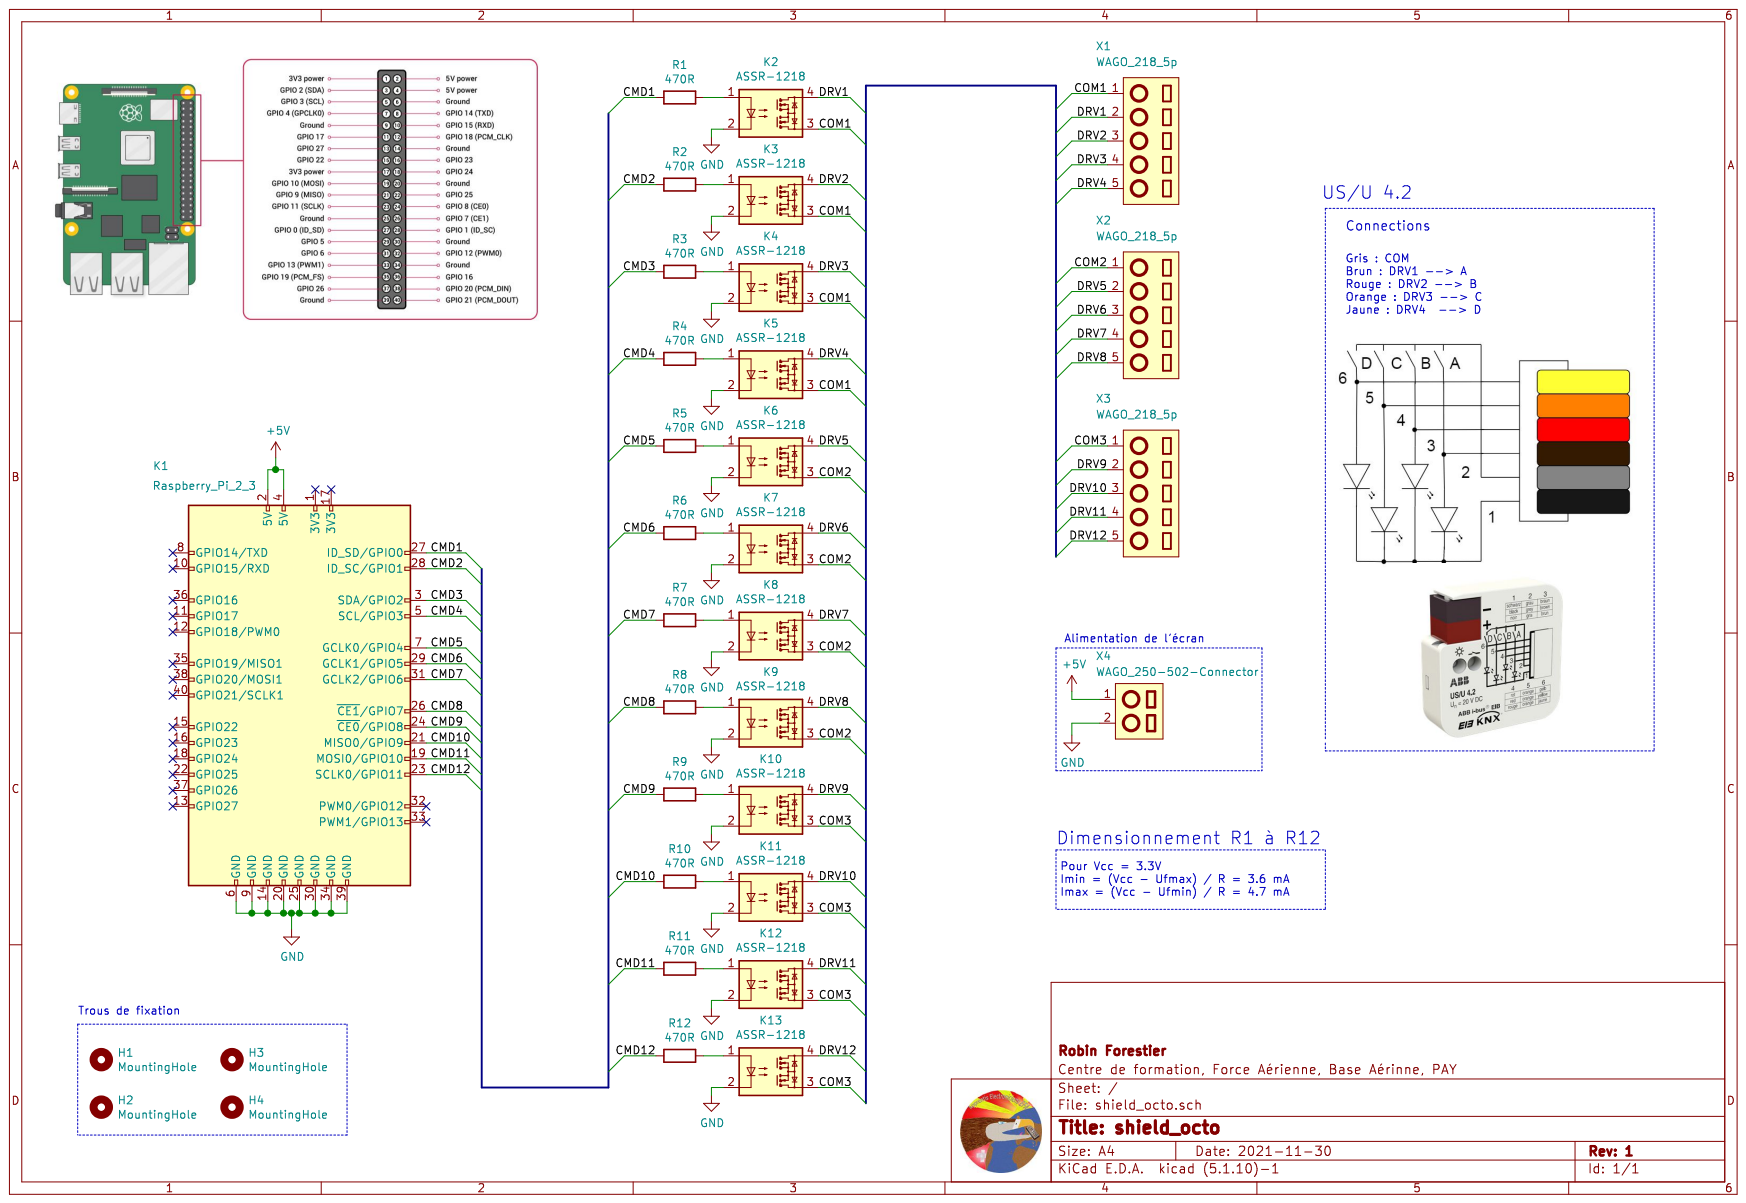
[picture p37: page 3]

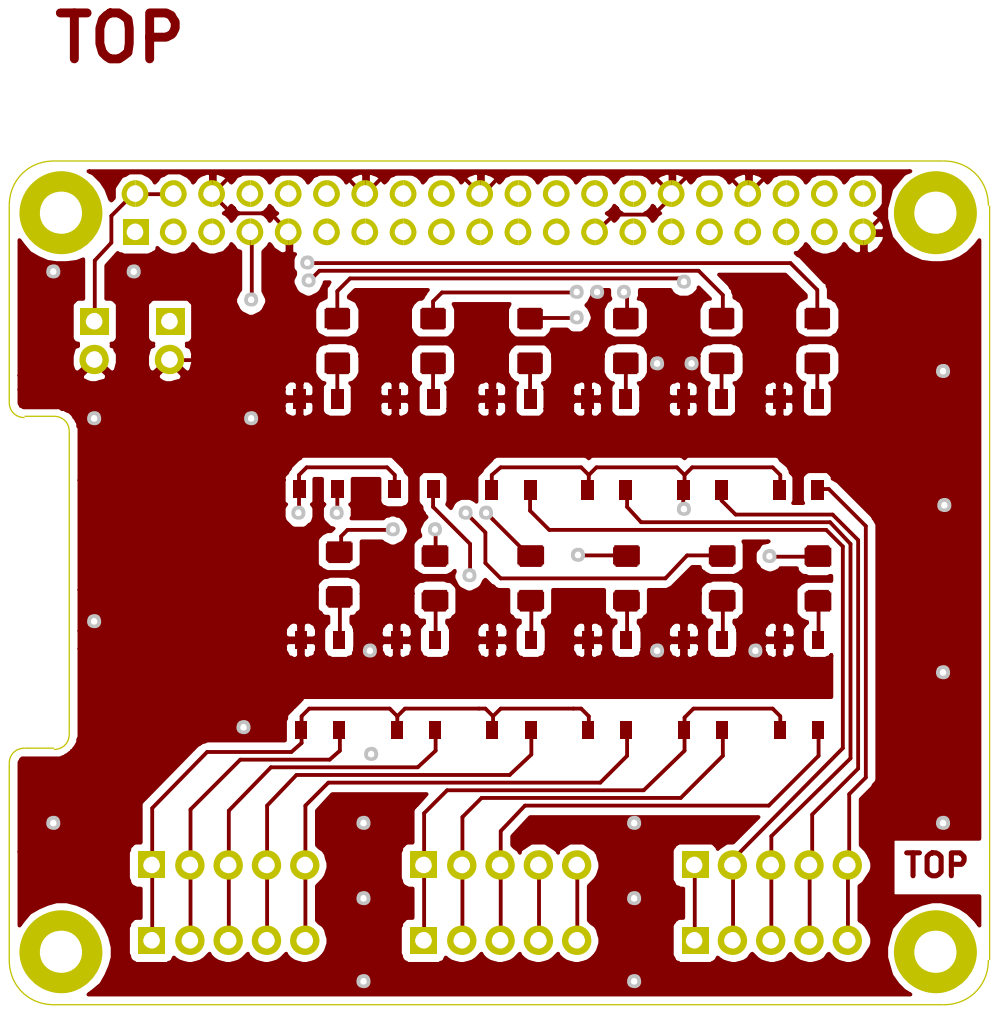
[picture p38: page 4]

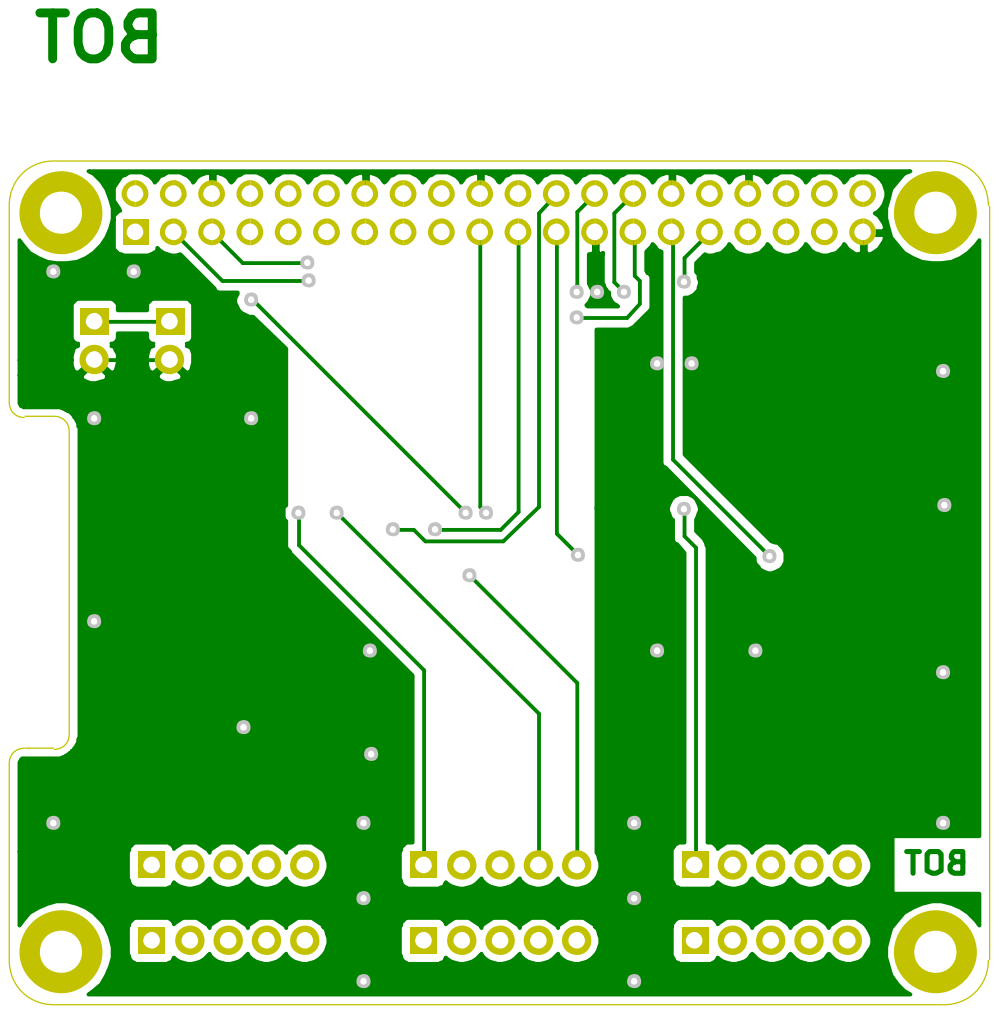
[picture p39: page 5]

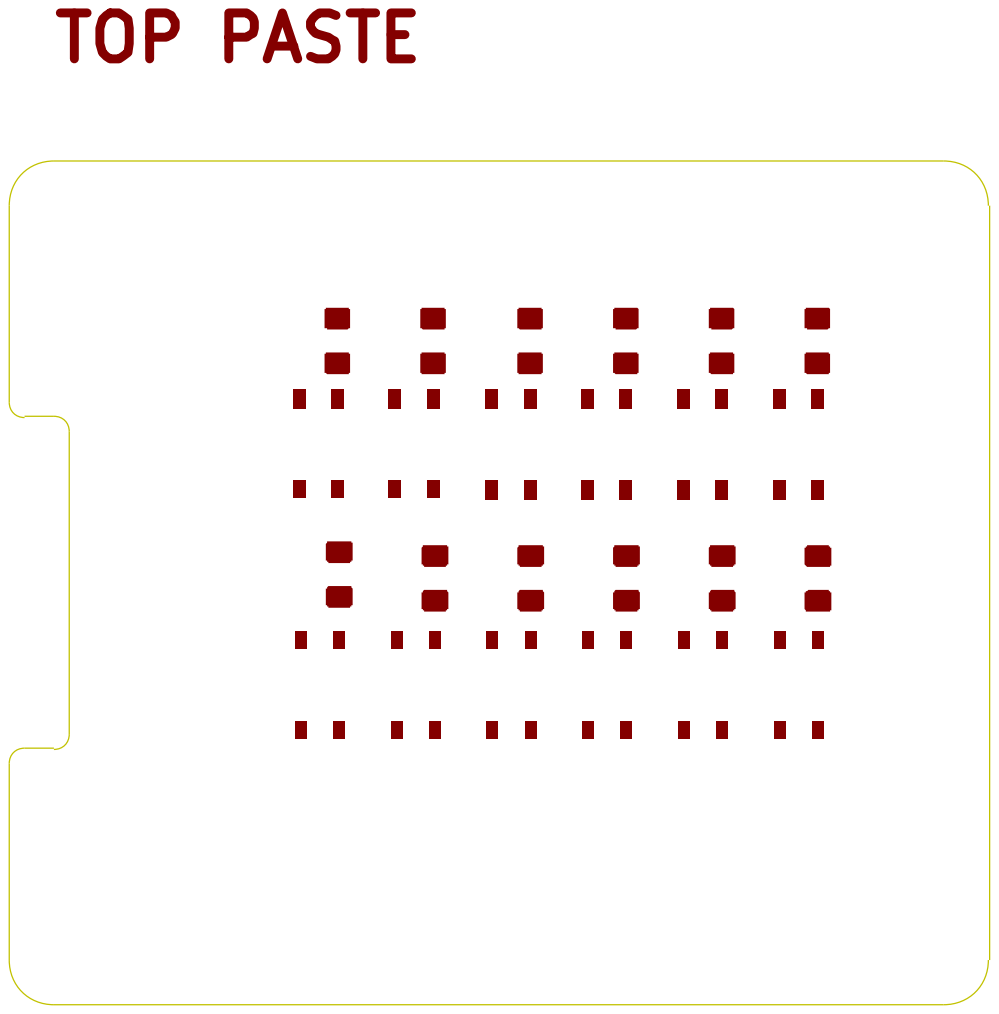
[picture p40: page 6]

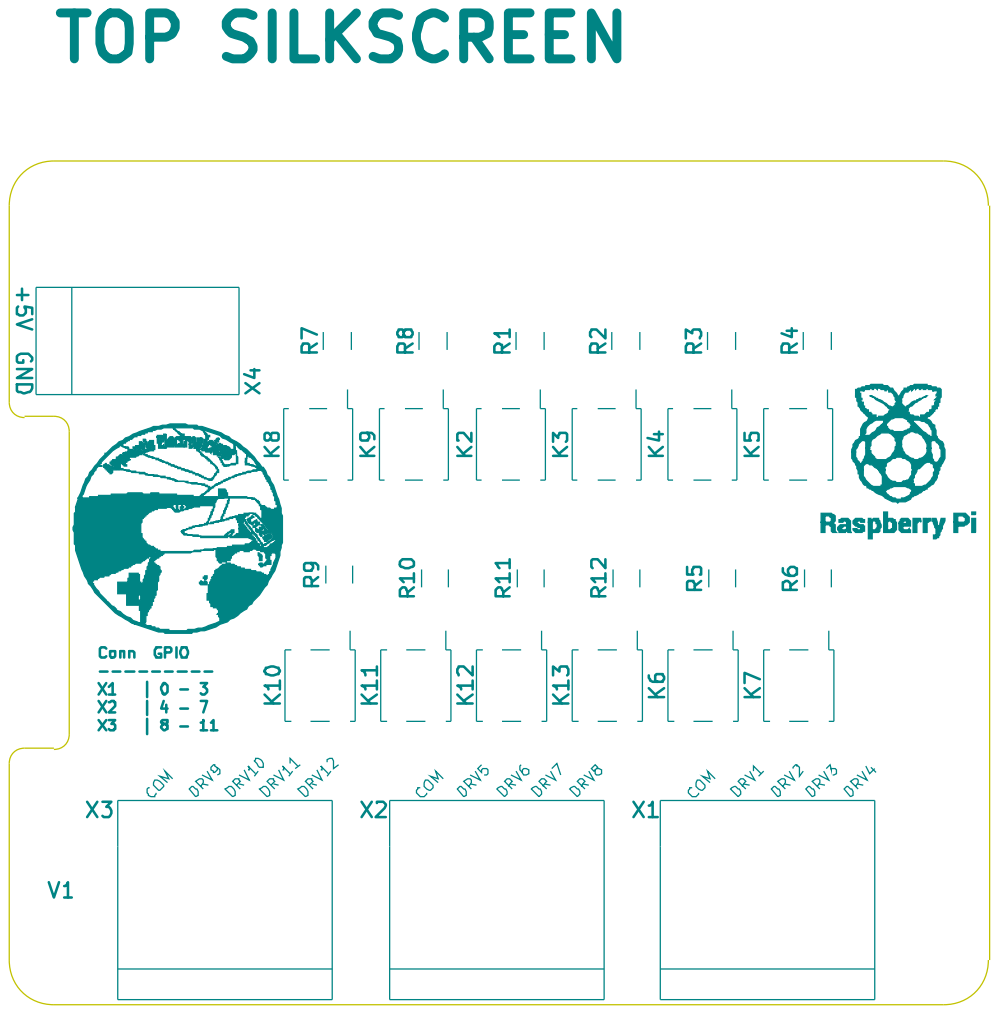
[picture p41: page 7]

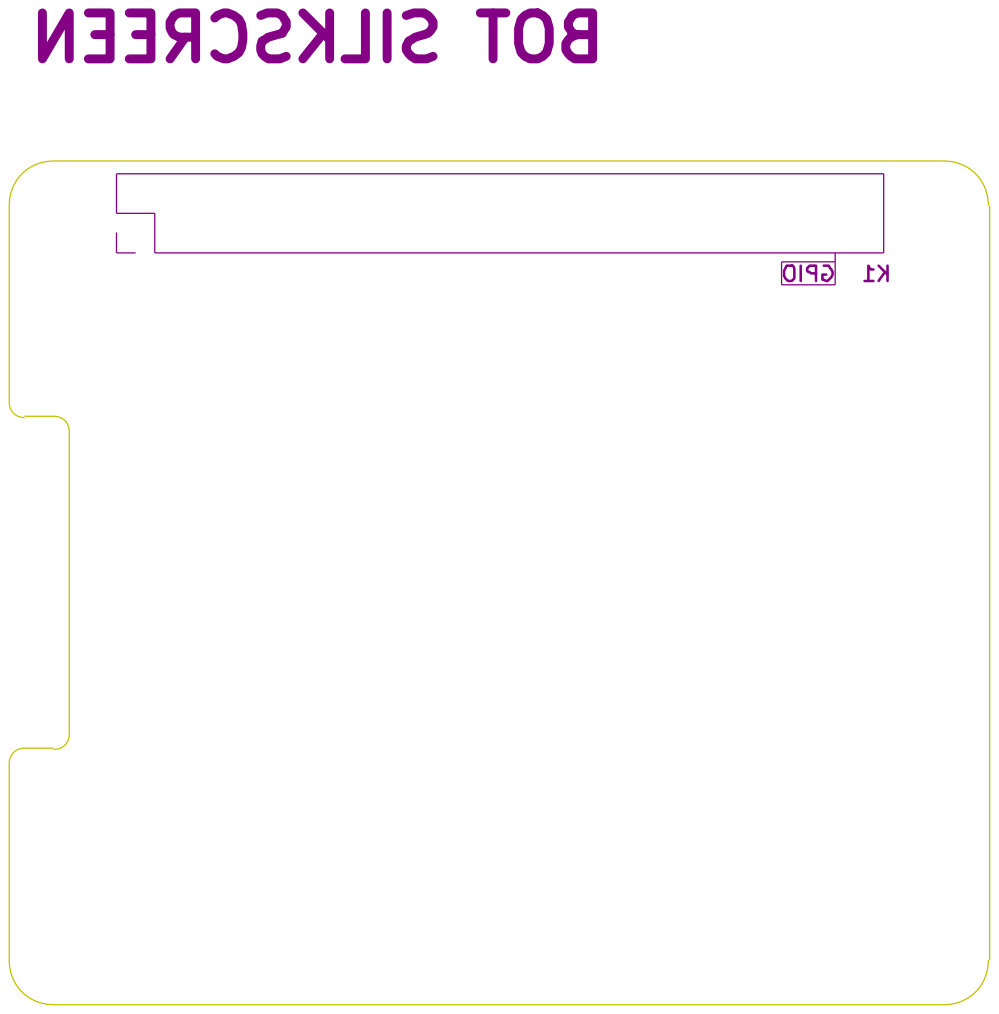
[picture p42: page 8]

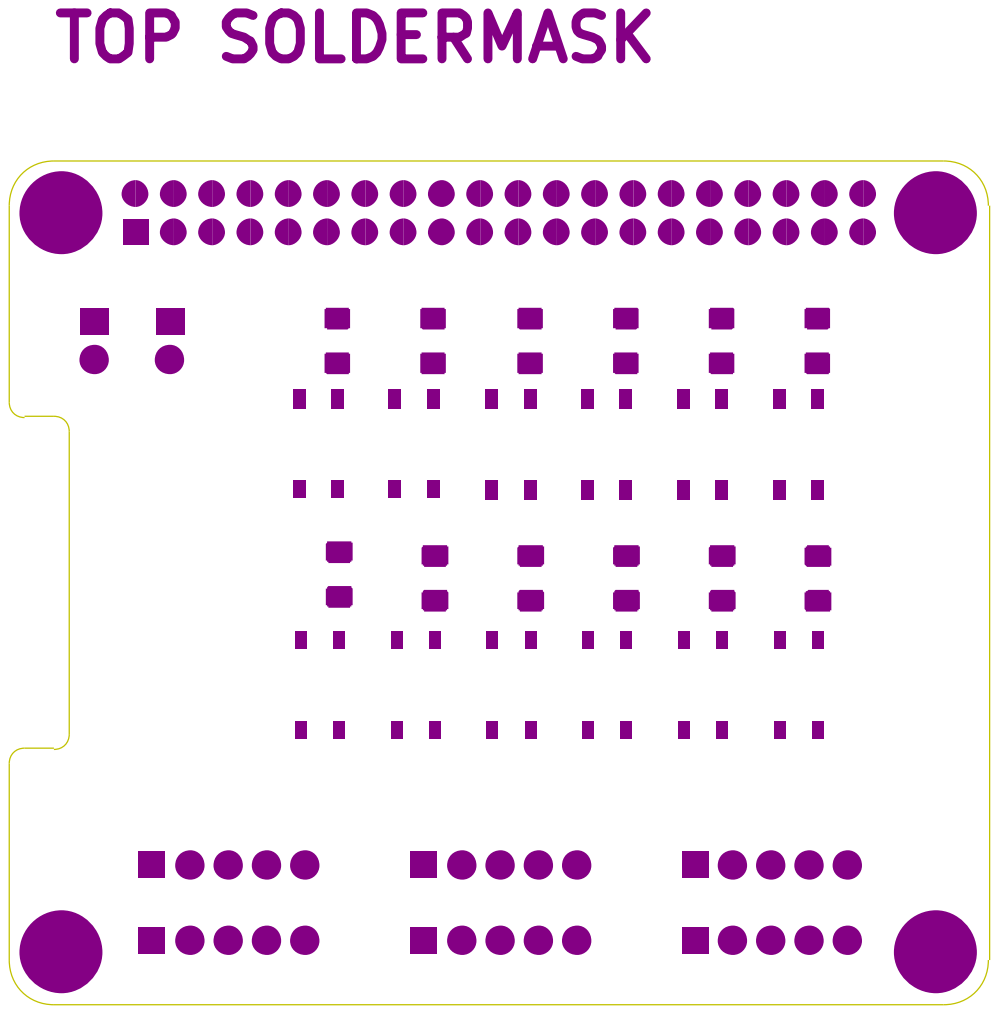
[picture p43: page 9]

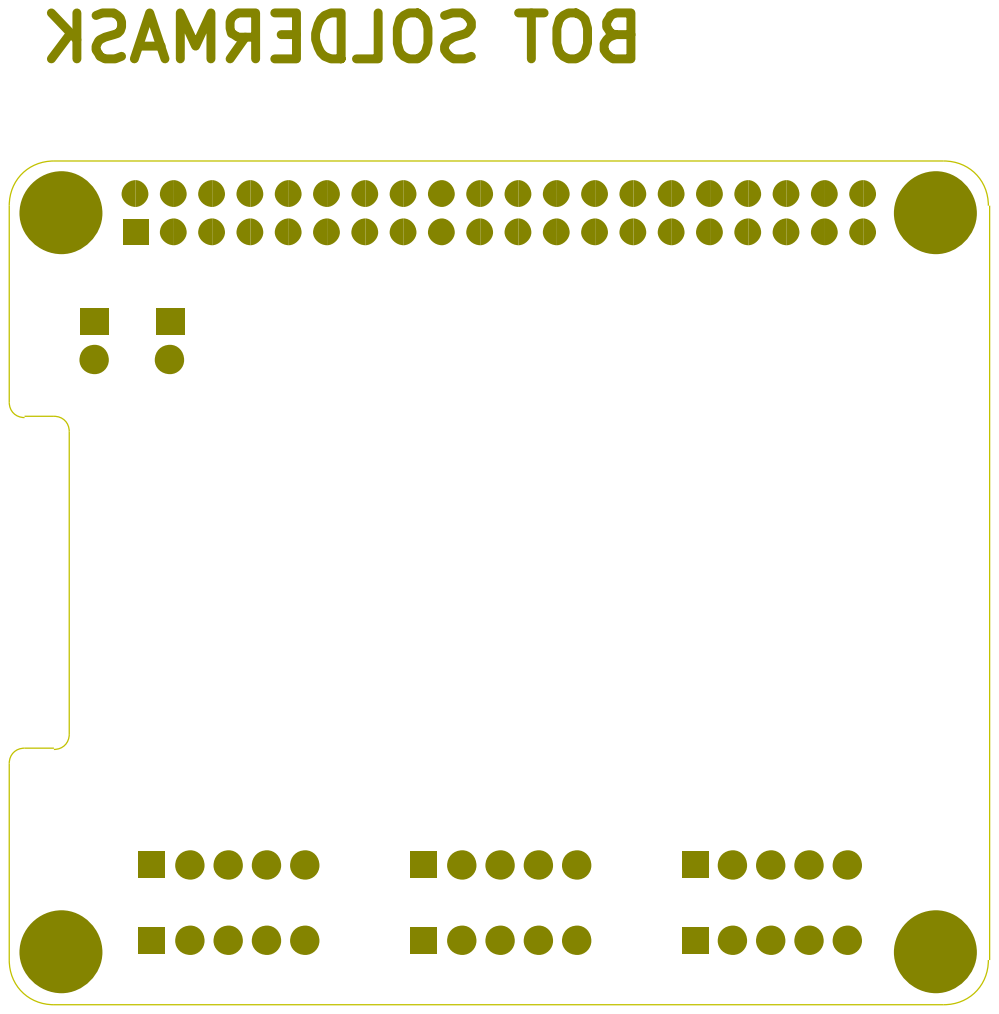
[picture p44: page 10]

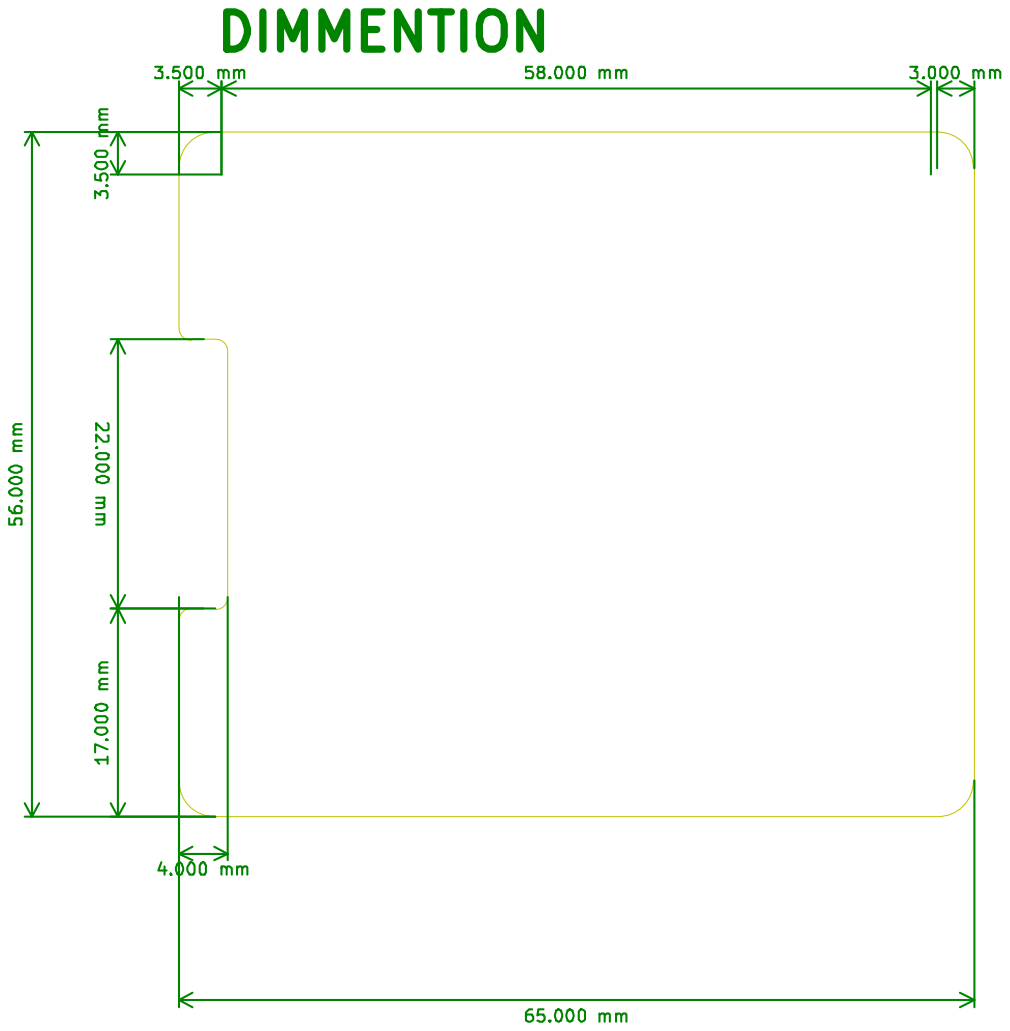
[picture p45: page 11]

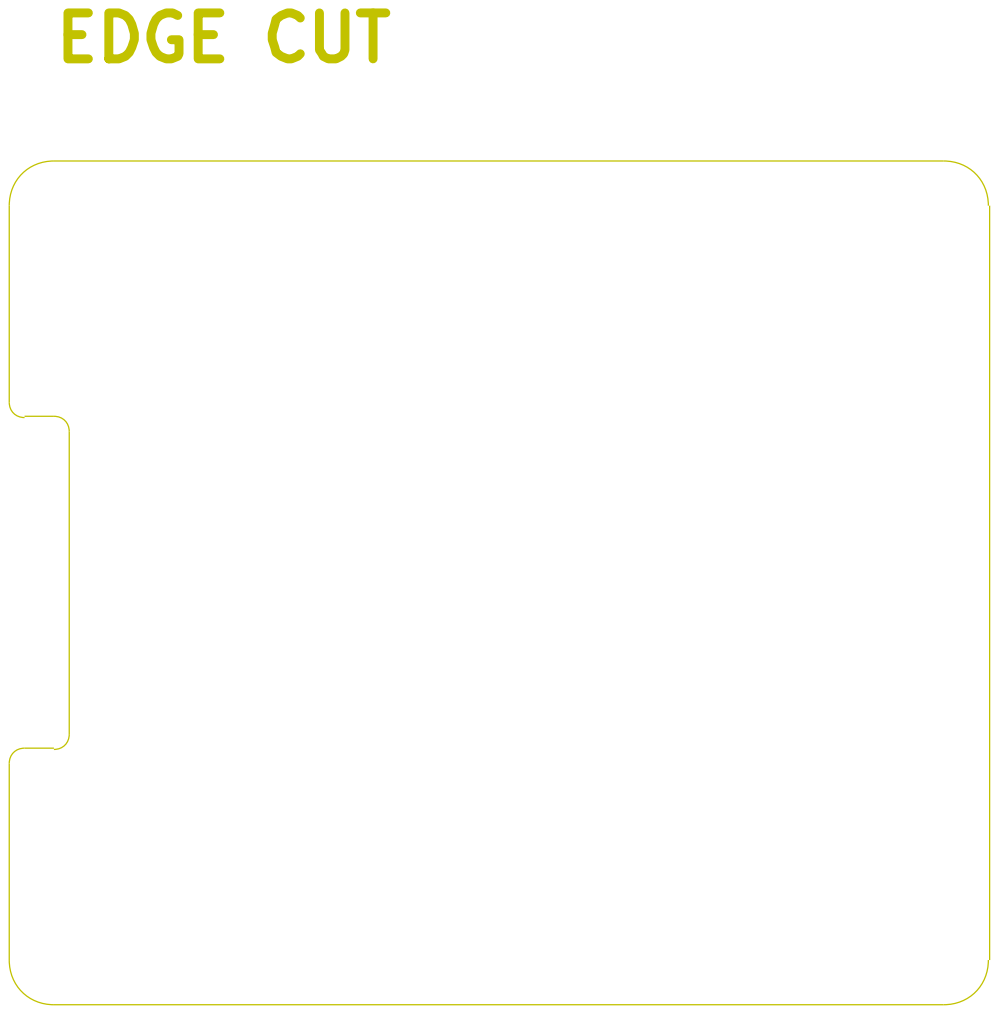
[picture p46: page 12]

Drill Map: 0.400mm / 0.0157" (41 holes) 1.000mm / 0.0394" (74 holes) 2.700mm / 0.1063" (4 holes)










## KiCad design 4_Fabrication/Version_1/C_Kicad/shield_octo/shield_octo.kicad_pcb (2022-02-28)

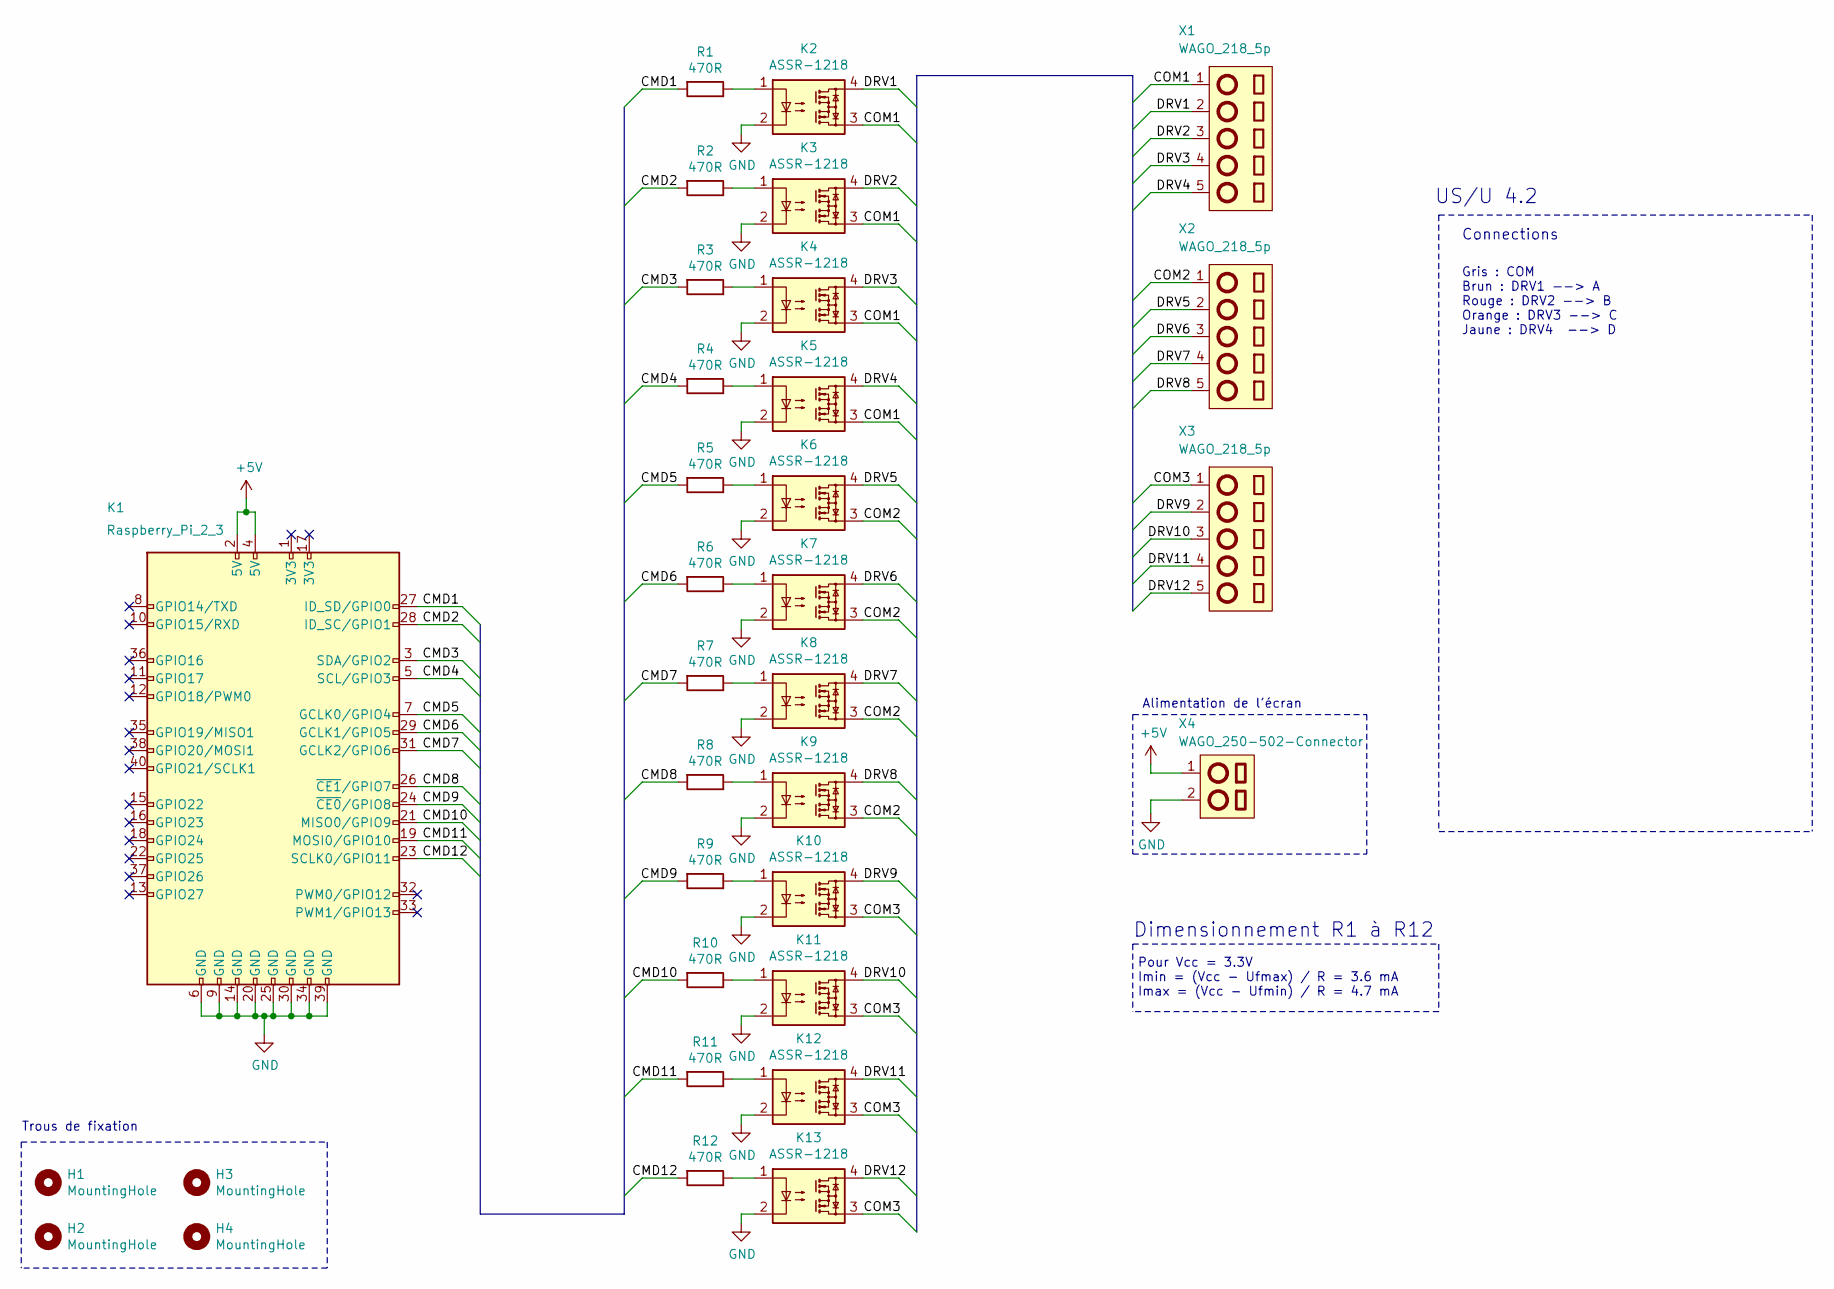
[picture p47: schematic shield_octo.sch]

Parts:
H1, H2, H3, H4: MountingHole; MountingHole_2.7mm_Pad
K1: Raspberry_Pi_2_3; PinSocket_2x20_P2.54mm_Vertical
K2, K3, K4, K5, K6, K7, K8, K9, K10, K11, K12, K13: ASSR-1218; SO-4_4.4x4.3mm_P2.54mm
R1, R2, R3, R4, R5, R6, R7, R8, R9, R10, R11, R12: 470R; R_1206_3216Metric_Pad1.42x1.75mm_HandSolder
X1, X2, X3: WAGO_218_5p; WAGO_218-505
X4: WAGO_250-502-Connector; Wago_218-502_MOR

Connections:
+5V: K1.2 (5V), K1.4 (5V), X4.1
/CMD1: K1.27 (ID_SD/GPIO0), R1.2
/CMD2: K1.28 (ID_SC/GPIO1), R2.2
/CMD3: K1.3 (SDA/GPIO2), R3.2
/CMD4: K1.5 (SCL/GPIO3), R4.2
/CMD5: K1.7 (GCLK0/GPIO4), R5.2
/CMD6: K1.29 (GCLK1/GPIO5), R6.2
/CMD7: K1.31 (GCLK2/GPIO6), R7.2
/CMD8: K1.26 (~CE1~/GPIO7), R8.2
/CMD9: K1.24 (~CE0~/GPIO8), R9.2
/CMD10: K1.21 (MISO0/GPIO9), R10.2
/CMD11: K1.19 (MOSI0/GPIO10), R11.2
/CMD12: K1.23 (SCLK0/GPIO11), R12.2
/COM1: K2.3, K3.3, K4.3, K5.3, X1.1
/COM2: K6.3, K7.3, K8.3, K9.3, X2.1
/COM3: K10.3, K11.3, K12.3, K13.3, X3.1
/DRV1: K2.4, X1.2
/DRV2: K3.4, X1.3
/DRV3: K4.4, X1.4
/DRV4: K5.4, X1.5
/DRV5: K6.4, X2.2
/DRV6: K7.4, X2.3
/DRV7: K8.4, X2.4
/DRV8: K9.4, X2.5
/DRV9: K10.4, X3.2
/DRV10: K11.4, X3.3
/DRV11: K12.4, X3.4
/DRV12: K13.4, X3.5
GND: K1.6 (GND), K1.9 (GND), K1.14 (GND), K1.20 (GND), K1.25 (GND), K1.30 (GND), K1.34 (GND), K1.39 (GND), K2.2, K3.2, K4.2, K5.2, K6.2, K7.2, K8.2, K9.2, K10.2, K11.2, K12.2, K13.2, X4.2
unnamed: K2.1, R1.1
unnamed: K3.1, R2.1
unnamed: K4.1, R3.1
unnamed: K5.1, R4.1
unnamed: K6.1, R5.1
unnamed: K7.1, R6.1
unnamed: K8.1, R7.1
unnamed: K9.1, R8.1
unnamed: K10.1, R9.1
unnamed: K11.1, R10.1
unnamed: K12.1, R11.1
unnamed: K13.1, R12.1

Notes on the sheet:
Dimensionnement R1 à R12
Pour Vcc = 3.3V Imin = (Vcc - Ufmax) / R = 3.6 mA Imax = (Vcc - Ufmin) / R = 4.7 mA
US/U 4.2
Alimentation de l'écran
Trous de fixation
Gris : COM Brun : DRV1 --> A Rouge : DRV2 --> B Orange : DRV3 --> C Jaune : DRV4 --> D
Connections

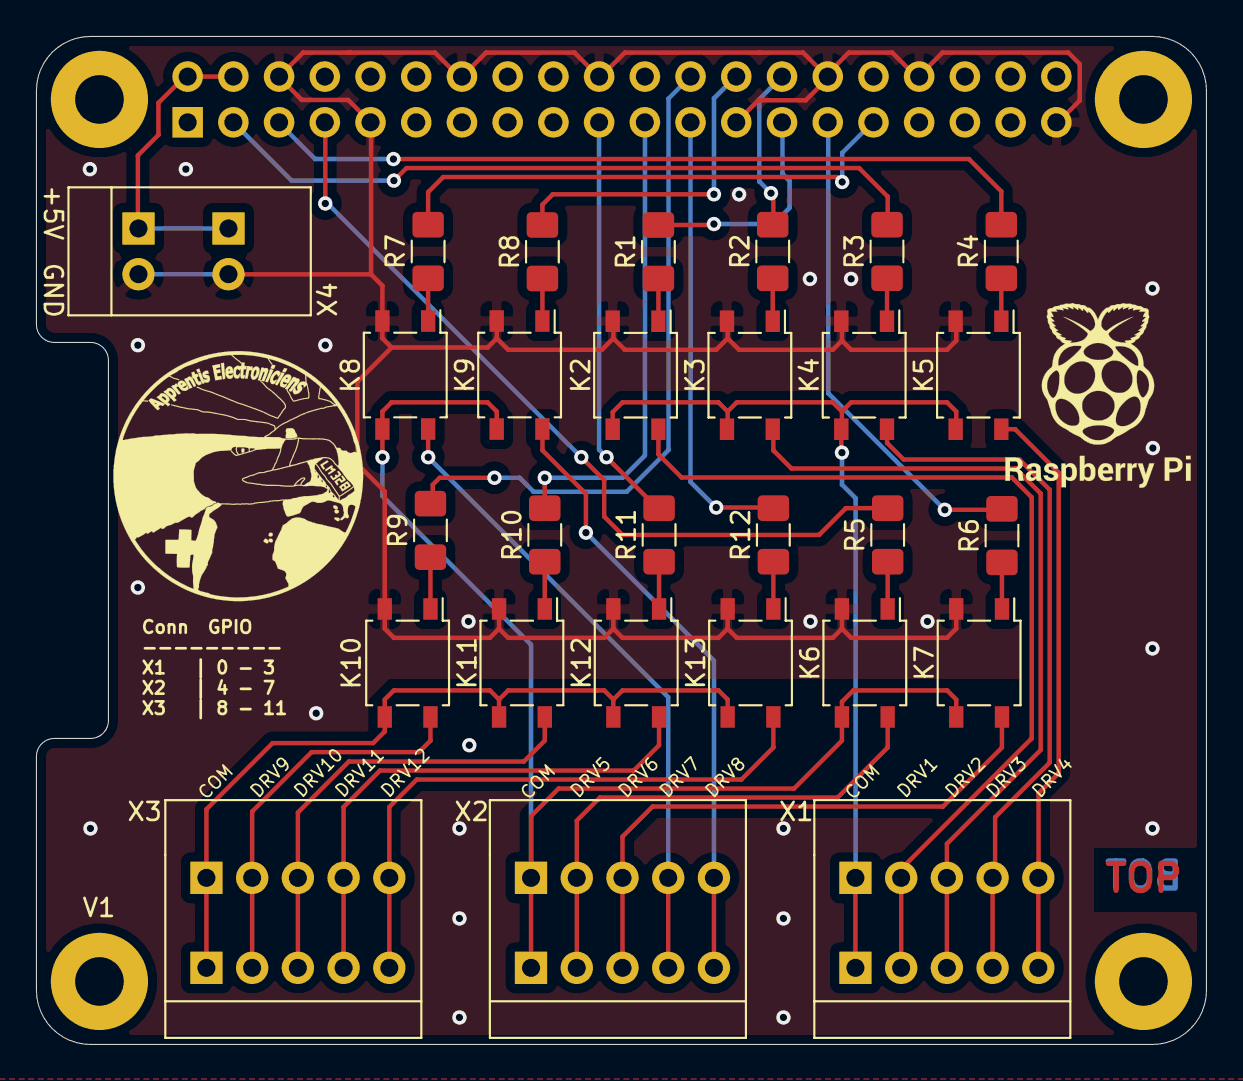
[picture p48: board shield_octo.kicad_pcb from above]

Board: 2 copper layers, 65.0 x 56.0 mm, 33 parts (1 on the bottom side), 41 nets.

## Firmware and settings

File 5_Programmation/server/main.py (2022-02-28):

"""
main.py | Robin Forestier | 2021 / 2022

Goal : Create a user interface to controle the light of the ELO's workshop.

Explanation :   I use Flask for create a Web server.
                A shield is plug on the Raspberry Pi (server) with optocoupleur to ABB module with the GPIO.

┌─────────────────────────────────┐
│ Raspberry Pi 3B+                │ ┌───────────────────────┐
│                            ┌──┐ │ │ Shield Octo           │
│                            │  │ │ │                       │
│          GPIO 2  |         │  │ │ │ X1 / DRV3 |           │
│          GPIO 3  |         │  │ │ │ X1 / DRV4 |           │
│          GPIO 4  |         │  │ │ │ X2 / DRV1 |           │
│                  |         │  │ │ │           |           │
│          GPIO 10 |         │  │ │ │ X3 / DRV3 |           │
│          GPIO 9  |         │  │ │ │ X3 / DRV2 |           │
│          GPIO 11 | GPIO 8  │  │ │ │ X3 / DRV4 | X3 / DRV1 │
│                  | GPIO 7  │  │ │ │           | X2 / DRV4 │
│          GPIO 0  | GPIO 1  │  │ │ │ X1 / DRV1 | X1 / DRV2 │
│          GPIO 5  |         │  │ │ │ X2 / DRV2 |           │
│          GPIO 6  |         │  │ │ │ X2 / DRV3 |           │
│                            │  │ │ └───────────────────────┘
│                            │  │ │
│                            └──┘ │
│                     ┌───────┐   │
│  ┌────┐   ┌────┐    │       │   │
│  │    │   │    │    │       │   │
└──┴────┴───┴────┴────┴───────┴───┘

.. Liens::
    GitLab : http://172.16.32.230/Forestier/controle-des-lumieres-knx \n
    XWiki : https://xwiki.serverelo.org/xwiki/bin/view/Centre%20de%20Formation%20ELO/Projets/Controle%20des%20lumières%20KNX/
"""

from flask import Flask, render_template, request, session, url_for, redirect, flash, abort
from flask_sqlalchemy import SQLAlchemy
from flask_session import Session
import time
import datetime
import threading
import csv
import os
import logging
from werkzeug.exceptions import HTTPException

rpi = False
"""
rpi is used to know if the programm is running on a Raspberry Pi or not. \n
rpi = True --> run on Raspberry Pi. \n
esle : False
"""
try:
    import RPi.GPIO as GPIO
    GPIO.setmode(GPIO.BCM)
    GPIO.setwarnings(False)

    # GPIO 0 to 11 in output mode at 0
    for i in range(12):
        GPIO.setup(i, GPIO.OUT, initial=GPIO.LOW)

    #it's a raspberry pi
    rpi = True
except :
    rpi = False

#Creating log file (log.log)
logging.basicConfig(filename="log.log", format='%(asctime)s - %(levelname)s - %(message)s', level=logging.DEBUG)

#Creating flask app
app = Flask(__name__)

#Config
app.config.update(
    SECRET_KEY = 'somesecretkeythatonlyishouldknow',
    SQLALCHEMY_DATABASE_URI = "sqlite:///db.sqlite3",
    SQLALCHEMY_TRACK_MODIFICATIONS = False,
    SESSION_TYPE = 'sqlalchemy',
    SESSION_COOKIE_NAME = 'MyBeautifulCookies',
    SESSION_COOKIE_SAMESITE = 'Strict',
)

db = SQLAlchemy(app)
app.config['SESSION_SQLALCHEMY'] = db
sess = Session(app)

#creat the database
db.create_all()

authorize_ip = ["localhost", "127.0.0.1", "172.16.32.133"]
"""Ip of the server (for the local user) use to skip authentication."""

buttonSts_p1 = ["off"] * 8
"""value of all the page1 buttons"""
buttonSts_p2 = ["on"] * 8
"""value of all the page2 buttons"""
color = ["#333333"] * 8
"""color of the 8 neon"""
warning = ""
"""warning from the app to the server"""

#Path to config file "/config.csv"
if rpi:
    path_to_csv = "/home/pi/controle-des-lumieres-knx/5_Programmation/server/config.csv"
else:
    path_to_csv = "C:/Users/FIX-4/Desktop/server_v2/config.csv"

class User:
    """
    User : creat different user for the login.
    """
    def __init__(self, id, username, password):
        """
        Parameters
        ----------
        id : int
            A basic id for eache login.
        username : str
            The username for the login.
        password : str
            The password of the login.
        """
        self.id = id
        self.username = username
        self.password = password

users = []

"""
user :
    elo - basic user / can only modifie light
    admin - all acces (settings acces)
    local - only used for the raspberry why the tuchscreen (server) / can't acces to settings / don't have to login.
"""
users.append(User(id=1, username='elo', password='elo'))
users.append(User(id=2, username='admin', password='admin'))
users.append(User(id=3, username='local', password='local'))

def gpio_modif():
    """
    modif all the GPIO by looking into buttonSts_p1[]

    Parameters
    ----------
    ...
    """
    if rpi:
        for i in range(8):
            if buttonSts_p1[i] == "off":
                #OFF
                GPIO.output(i, 0)
            else:
                #ON
                GPIO.output(i, 1)
                #time.sleep(1)     #security time for fuses
    else:
        pass


def getTime():
    """
    Get time on format : HH:MM

    Parameters
    ----------
    ...

    Returns
    ----------
    current_time : str
        The current time in format HH:MM
    """
    t = time.localtime()
    current_time = time.strftime("%H:%M", t)

    return current_time

@app.errorhandler(HTTPException)
def handle_exception(e):
    """handle_exception : all http error are show on the 404.html page"""
    e = str(e) #404 not ...  :  The request URL ...
    code = e.split(":") #404 Not Found

    return render_template('404.html', error=code[1], title=code[0]), code[0][0:3]

@app.route("/login", methods=['POST', 'GET'])
@app.route("/", methods=['POST', 'GET'])
def login():
    """
    login page

    Receive from POST : username / password
    We first check if username existe and after password.
    If it's a bad username or pass we flash the error.

    Parameters
    ----------
    ...

    Returns
    ----------
    login.html : str
        Page login in html and (css).
    time : str
        The current time.
    warning : str
        The différent warning.
    """
    current_time = getTime()
    ip = request.environ.get('HTTP_X_REAL_IP', request.remote_addr)

    #check for autorized ip
    for i in authorize_ip:
        if ip == i:
            logging.info("creat local user" + str(ip))
            session['user_id'] = 3
            return redirect(url_for('page1'))

    #if already login
    if session.get("user_id") is not None:
        return redirect(url_for('page1'))

    if request.method == 'POST':
        session.pop('user_id', None)

        username = request.form['username']
        password = request.form['password']

        try:
            user = [x for x in users if x.username == username][0]
            if user and user.password == password:
                session['user_id'] = user.id
                logging.info("New login username : " + username + " ip : " + str(ip))
                #Login accepted
                return redirect(url_for('page1'))
            elif user.password != password:
                #bad password / log it / and flash the error
                logging.warning("bad password : " + username + " ip : " + str(ip))
                flash("Bad password")

            return redirect(url_for('login'))

        except:
            #bad username / log it / and flash the error
            logging.warning("bad username : " + username + " ip : " + str(ip))
            flash("Bad username")
            return redirect(url_for('login'))

    return render_template("login.html", time=current_time, warning=warning)

@app.route("/page1", methods = ['POST', 'GET'])
def page1():
    """
    page1

    The page1 show on the left a map of the lights and on the right 9 buttons.

    Parameters
    ----------
    ...

    Returns
    ----------
    page1.html : str
        Page page1 in html and (css).
    button : list
        List of the state of the buttons.
    color : list
        List of neon colors on the map.
    time : str
        The current time.
    warning : str
        The différent warning.
    """
    current_time = getTime()

    # check the id for the session and redirect to loggin.
    if session.get("user_id") == None:
        return redirect(url_for('login'))

    if all(elem == "on" for elem in buttonSts_p1):
        buttonSts_p2[0] = "on"
    else:
        buttonSts_p2[0] = "off"

    if request.method == 'POST':
        if request.form['button_p1'] == '1':
            if buttonSts_p1[0] == "on":
                buttonSts_p1[0] = "off"
                color[0] = "#333333"
            else:
                buttonSts_p1[0] = "on"
                color[0] = "#FFFFFF"
        elif request.form['button_p1'] == '2':
            if buttonSts_p1[1] == "on":
                buttonSts_p1[1] = "off"
                color[1] = "#333333"
            else:
                buttonSts_p1[1] = "on"
                color[1] = "#FFFFFF"
        elif request.form['button_p1'] == '3':
            if buttonSts_p1[2] == "on":
                buttonSts_p1[2] = "off"
                color[2] = "#333333"
            else:
                buttonSts_p1[2] = "on"
                color[2] = "#FFFFFF"
        elif request.form['button_p1'] == '4':
            if buttonSts_p1[3] == "on":
                buttonSts_p1[3] = "off"
                color[3] = "#333333"
            else:
                buttonSts_p1[3] = "on"
                color[3] = "#FFFFFF"
        elif request.form['button_p1'] == '5':
            if buttonSts_p1[4] == "on":
                buttonSts_p1[4] = "off"
                color[4] = "#333333"
            else:
                buttonSts_p1[4] = "on"
                color[4] = "#FFFFFF"
        elif request.form['button_p1'] == '6':
            if buttonSts_p1[5] == "on":
                buttonSts_p1[5] = "off"
                color[5] = "#333333"
            else:
                buttonSts_p1[5] = "on"
                color[5] = "#FFFFFF"
        elif request.form['button_p1'] == '7':
            if buttonSts_p1[6] == "on":
                buttonSts_p1[6] = "off"
                color[6] = "#333333"
            else:
                buttonSts_p1[6] = "on"
                color[6] = "#FFFFFF"
        elif request.form['button_p1'] == '8':
            if buttonSts_p1[7] == "on":
                buttonSts_p1[7] = "off"
                color[7] = "#333333"
            else:
                buttonSts_p1[7] = "on"
                color[7] = "#FFFFFF"
        elif request.form['button_p1'] == 'page_2':
            return redirect(url_for('page2'))
        else:
            pass

        gpio_modif()

    return render_template('page1.html', button=buttonSts_p1, color=color, time=current_time, warning=warning)

@app.route("/page2", methods = ['POST', 'GET'])
def page2():
    """
    page2

    The page2 show on the left a map of the lights and on the right 9 buttons.

    Parameters
    ----------
    ...

    Returns
    ----------
    page2.html : str
        Page page1 in html and (css).
    button : list
        List of the state of the buttons.
    color : list
        List of neon colors on the map.
    time : str
        The current time.
    warning : str
        The différent warning.
    """
    current_time = getTime()

    #check the id for the session and redirect to loggin.
    if session.get("user_id") == None:
        return redirect(url_for('login'))

    if request.method == 'POST':
        if request.form['button_p1'] == '1':
            buttonSts_p2[0] = "on"
            for i in range(8):
                buttonSts_p1[i] = "on"
                color[i] = "#FFFFFF"
        elif request.form['button_p1'] == '2':
            buttonSts_p2[1] = "off"
            for i in range(8):
                buttonSts_p1[i] = "off"
                buttonSts_p2[i] = "off"
                color[i] = "#333333"
        elif request.form['button_p1'] == '3':
            buttonSts_p2[0] = "off"
            buttonSts_p2[1] = "off"

            for i in range(0, 8, 2):
                color[i] = "#FFFFFF"
                color[i + 1] = "#333333"

                buttonSts_p1[i] = "on"
                buttonSts_p1[i + 1] = "off"
        elif request.form['button_p1'] == '4':
            buttonSts_p2[0] = "off"
            buttonSts_p2[1] = "off"

            for i in range(0, 8):
                if i < 3:
                    color[i] = "#FFFFFF"
                    buttonSts_p1[i] = "on"
                else :
                    color[i] = "#333333"
                    buttonSts_p1[i] = "off"
        elif request.form['button_p1'] == '5':
            buttonSts_p2[0] = "off"
            buttonSts_p2[1] = "off"

            for i in range(0, 8):
                if i > 3 and i != 7:
                    color[i] = "#FFFFFF"
                    buttonSts_p1[i] = "on"
                else:
                    color[i] = "#333333"
                    buttonSts_p1[i] = "off"

        elif request.form['button_p1'] == 'page_1':
            return redirect(url_for('page1'))
        else:
            pass

        gpio_modif()


    return render_template('page2.html', button=buttonSts_p2, color=color, time=current_time, warning=warning)

@app.route("/settings", methods = ['POST', 'GET'])
def settings():
    """
    settings

    The settings page can only be acces via admin login.

    Parameters
    ----------
    ...

    Returns
    ----------
    settings.html : str
        Page page1 in html and (css).
    time : str
        The current time.
    warning : str
        The différent warning.
    """

    """
    Get the id for the session.
    If == None --> go to login.
    If == 3 (local) --> go to page 1.
    If == 1 (elo) --> remove the id / error 418.
    """
    id = session.get("user_id")

    if id is None:
        return redirect(url_for('login'))
    elif id == 3:
        return redirect(url_for('page1'))
    elif id == 1:
        session.pop("user_id")
        abort(418) # 🍵

    current_time = getTime()

    # Check all settings via a form
    # Settings :
    #           Auto on  -> turn on at a certain time
    #           Auto off -> turn off at a certain time
    if request.method == 'POST':
        check1 = request.form.get('Auto on')
        time1 = request.form.get('time Auto on')
        check2 = request.form.get('Auto off')
        time2 = request.form.get('time Auto off')

        file = open(path_to_csv, "w", newline='')
        header = ['name','state','param1']
        csvf = csv.DictWriter(file, fieldnames=header)

        csvf.writeheader()
        csvf.writerow({'name': 'Auto on', 'state': check1, 'param1': time1})
        csvf.writerow({'name': 'Auto off', 'state': check2, 'param1': time2})

        file.close()

        return redirect(url_for('page1'))

    with open(path_to_csv, "r") as f:
        csvreader = csv.reader(f)
        header = next(csvreader)
        rows = []
        for row in csvreader:
            rows.append(row)

    f.close()

    return render_template('settings.html', time=current_time, settings=rows, warning=warning)

@app.before_first_request
def activate_job():
    """
    activate_job

    Fonction to run job on backround of the web server (with thread)

    Parameters
    ----------
    ...

    Returns
    ----------
    ...
    """
    def run_job():
        """
        run_job

        Run background job (run every minute).
        Auto - on/off
        Check temperature of the Raspberry Pi

        Parameters
        ----------
        ...

        Returns
        ----------
        ...
        """

        logging.debug("starting while loop")
        while True:
            t = getTime()

            with open(path_to_csv, "r") as f:
                csvreader = csv.reader(f)
                header = next(csvreader)
                rows = []
                for row in csvreader:
                    rows.append(row)
            f.close()

            """
            if day is on monday to friday (0 to 4 // 0 is monday)
            check for auto all on / off.
            """
            day = datetime.datetime.today().weekday()
            if rows[0][1] == 'on' and t == rows[0][2] and day < 5:
                logging.info("All light ON Automaticly")
                buttonSts_p2[0] = "on"
                for i in range(8):
                    buttonSts_p1[i] = "on"
                    color[i] = "#FFFFFF"
                gpio_modif()

            if rows[1][1] == 'on' and t == rows[1][2] and day < 5:
                logging.info("All light ON Automaticly")
                buttonSts_p2[1] = "off"
                for i in range(8):
                    buttonSts_p1[i] = "off"
                    buttonSts_p2[i] = "off"
                    color[i] = "#333333"
                gpio_modif()

            #Check temperature warning
            if rpi:
                with open('/sys/class/thermal/thermal_zone0/temp', 'r') as ftemp:
                    global warning
                    temp = int(ftemp.read()) / 1000
                    if temp > 60:
                        logging.warning("Temp = " + str(int(temp)) + "°")
                        warning = "Temp = " + str(int(temp)) + "°"
                    else:
                        warning = ""

            time.sleep(60)

    thread = threading.Thread(target=run_job)
    thread.start()

if __name__ == "__main__":
    logging.info(" *** Strating server *** ")
    app.run(host='0.0.0.0', port=80, debug=False)
    GPIO.cleanup()

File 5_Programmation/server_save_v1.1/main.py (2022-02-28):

#main.py | Robin Forestier | 2021 / 2022

from flask import Flask, g, render_template, request, session, url_for, redirect
import time
import datetime
import threading
import csv
import os
import logging

import RPi.GPIO as GPIO

logging.basicConfig(filename="log.log", format='%(asctime)s - %(levelname)s - %(message)s', level=logging.DEBUG) 

GPIO.setmode(GPIO.BCM)
GPIO.setwarnings(False)

#GPIO 0 to 11 in output mode at 0
for i in range(12):
    GPIO.setup(i, GPIO.OUT, initial=GPIO.LOW)

app = Flask(__name__)
app.secret_key = 'somesecretkeythatonlyishouldknow'
app.session_cookie_name = 'MyBeautifulCookies'

authorize_ip = ["localhost", "127.0.0.1", "172.16.32.133"]

buttonSts_p1 = ["/static/img/img_off.png"] * 8
buttonSts_p2 = ["/static/img/img_off.png"] * 8
color = ["#333333"] * 8
warning = ""

class User:
    def __init__(self, id, username, password):
        self.id = id
        self.username = username
        self.password = password

    def __repr__(self):
        return f'<User: {self.username}>'

users = []
users.append(User(id=1, username='elo', password='elo'))
users.append(User(id=2, username='admin', password='admin'))
users.append(User(id=3, username='local', password='local'))

def gpio_modif():

    for i in range(8):
        if buttonSts_p1[i] == "/static/img/img_off.png":
            #OFF
            GPIO.output(i, 0)
        else:
            #ON
            GPIO.output(i, 1)
            #time.sleep(1)     #security time for fuses

def getTime():
    t = time.localtime()
    current_time = time.strftime("%H:%M", t)

    return current_time

@app.before_request
def before_request():
    g.user = None

    ip = request.environ.get('HTTP_X_REAL_IP', request.remote_addr)

    if 'user_id' in session :
        #logging.debug("reconnect " + str(ip))
        user = [x for x in users if x.id == session['user_id']][0]
        g.user = user

    else :
        for i in authorize_ip:
            if ip == i:
                if 'user_id' in session:
                    #logging.debug("reconect as local " + str(ip))
                    user = [x for x in users if x.id == session['user_id']][0]
                    g.user = user
                
                else :
                    logging.info("creat local user" + str(ip))
                    session.pop('user_id', None)
                    session['user_id'] = 3
                    return redirect(url_for('page1'))

@app.route("/", methods=['POST', 'GET'])
def login():
    current_time = getTime()

    if request.method == 'POST':
        session.pop('user_id', None)

        username = request.form['username']
        password = request.form['password']

        ip = request.environ.get('HTTP_X_REAL_IP', request.remote_addr)

        try:
            user = [x for x in users if x.username == username][0]
            try:
                if user and user.password == password:
                    session['user_id'] = user.id
                    logging.info("New login username : " + username + " ip : ", str(ip))
                    return redirect(url_for('page1'))
            except:
                logging.warning("bad password : " + username + " ip : " + str(ip))
                return redirect(url_for('login'))
        except:
            logging.warning("bad username : " + username + " ip : " + str(ip))
            return redirect(url_for('login'))

    return render_template("login.html", time=current_time, warning=warning)

@app.route("/page1", methods = ['POST', 'GET'])
def page1():
    current_time = getTime()

    if not g.user:
        return redirect(url_for('login'))

    if all(elem == "/static/img/img_on.png" for elem in buttonSts_p1):
        buttonSts_p2[0] = "/static/img/img_on.png"
    else:
        buttonSts_p2[0] = "/static/img/img_off.png"

    if request.method == 'POST':
        if request.form['button_p1'] == '1':
            if buttonSts_p1[0] == "/static/img/img_on.png":
                buttonSts_p1[0] = "/static/img/img_off.png"
                color[0] = "#333333"
            else:
                buttonSts_p1[0] = "/static/img/img_on.png"
                color[0] = "#FFFFFF"
        elif request.form['button_p1'] == '2':
            if buttonSts_p1[1] == "/static/img/img_on.png":
                buttonSts_p1[1] = "/static/img/img_off.png"
                color[1] = "#333333"
            else:
                buttonSts_p1[1] = "/static/img/img_on.png"
                color[1] = "#FFFFFF"
        elif request.form['button_p1'] == '3':
            if buttonSts_p1[2] == "/static/img/img_on.png":
                buttonSts_p1[2] = "/static/img/img_off.png"
                color[2] = "#333333"
            else:
                buttonSts_p1[2] = "/static/img/img_on.png"
                color[2] = "#FFFFFF"
        elif request.form['button_p1'] == '4':
            if buttonSts_p1[3] == "/static/img/img_on.png":
                buttonSts_p1[3] = "/static/img/img_off.png"
                color[3] = "#333333"
            else:
                buttonSts_p1[3] = "/static/img/img_on.png"
                color[3] = "#FFFFFF"
        elif request.form['button_p1'] == '5':
            if buttonSts_p1[4] == "/static/img/img_on.png":
                buttonSts_p1[4] = "/static/img/img_off.png"
                color[4] = "#333333"
            else:
                buttonSts_p1[4] = "/static/img/img_on.png"
                color[4] = "#FFFFFF"
        elif request.form['button_p1'] == '6':
            if buttonSts_p1[5] == "/static/img/img_on.png":
                buttonSts_p1[5] = "/static/img/img_off.png"
                color[5] = "#333333"
            else:
                buttonSts_p1[5] = "/static/img/img_on.png"
                color[5] = "#FFFFFF"
        elif request.form['button_p1'] == '7':
            if buttonSts_p1[6] == "/static/img/img_on.png":
                buttonSts_p1[6] = "/static/img/img_off.png"
                color[6] = "#333333"
            else:
                buttonSts_p1[6] = "/static/img/img_on.png"
                color[6] = "#FFFFFF"
        elif request.form['button_p1'] == '8':
            if buttonSts_p1[7] == "/static/img/img_on.png":
                buttonSts_p1[7] = "/static/img/img_off.png"
                color[7] = "#333333"
            else:
                buttonSts_p1[7] = "/static/img/img_on.png"
                color[7] = "#FFFFFF"
        elif request.form['button_p1'] == 'page_2':
            return redirect(url_for('page2'))
        else:
            pass

        gpio_modif()

    return render_template('page1.html', button=buttonSts_p1, color=color, time=current_time, warning=warning)
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

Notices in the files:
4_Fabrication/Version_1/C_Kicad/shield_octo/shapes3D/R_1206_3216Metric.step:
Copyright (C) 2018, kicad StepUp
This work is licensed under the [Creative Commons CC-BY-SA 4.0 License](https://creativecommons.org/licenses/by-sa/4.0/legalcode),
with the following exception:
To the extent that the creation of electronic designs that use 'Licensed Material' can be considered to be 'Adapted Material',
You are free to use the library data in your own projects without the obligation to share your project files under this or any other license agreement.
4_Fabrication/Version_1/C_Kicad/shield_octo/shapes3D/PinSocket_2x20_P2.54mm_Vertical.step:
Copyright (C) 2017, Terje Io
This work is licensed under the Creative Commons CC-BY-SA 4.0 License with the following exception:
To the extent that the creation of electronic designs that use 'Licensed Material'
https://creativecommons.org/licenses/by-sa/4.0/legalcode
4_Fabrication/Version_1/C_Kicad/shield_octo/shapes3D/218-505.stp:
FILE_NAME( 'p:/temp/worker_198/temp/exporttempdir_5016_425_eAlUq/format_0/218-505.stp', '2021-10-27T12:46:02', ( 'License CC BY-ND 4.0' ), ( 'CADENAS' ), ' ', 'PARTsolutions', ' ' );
